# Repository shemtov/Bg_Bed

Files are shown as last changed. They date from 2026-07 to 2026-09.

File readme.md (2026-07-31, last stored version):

# BedSystem — clean start

Rev 4 architecture. One central panel, two bed boxes, one audio node, all wired.

---

## The one rule that fixes the confusion

**The code file is always `src/main.cpp`. Always. In every project.**

The test number lives *inside* the file, on the `#define TEST_NUMBER` line and in
the banner at the top and bottom. It is never in the filename.

That means:

- There is never a question of "which .cpp is the current one" — there is only one.
- You never get "multiple definition of setup()" from two files sitting in `src/`.
- To move to a new test, you **overwrite** `src/main.cpp`. You never add a file.

The old names — `panel_test040.cpp`, `bedbox_test0009.cpp` — are what caused the
mess. They stop here.

---

## Structure

```
BedSystem/
├── panel/                  ESP32-8048S043 touchscreen at the headboard
│   ├── platformio.ini
│   ├── include/lv_conf.h   <-- YOU MUST SUPPLY THIS
│   └── src/main.cpp        TEST 041  (ready)
│
├── bedbox/                 QuinLED-ESP32 + L298N under each bed
│   ├── platformio.ini      (your real TEST 0009 config)
│   └── src/main.cpp        <-- YOU MUST SUPPLY THIS
│
└── audionode/              WT32-ETH01 + PCM5102A, by the soundbar
    ├── platformio.ini      (ready)
    └── src/main.cpp        (not written yet — TEST 001)
```

Each of the three folders is a **separate PlatformIO project**. Open them one at a
time in VS Code with **File → Open Folder**, pointing at `panel`, `bedbox` or
`audionode` — never at `BedSystem` itself.

You can rename the `BedSystem` folder to anything you like. PlatformIO only cares
about the folder that directly contains `platformio.ini`.

---

## Three files you must bring from your PC

I cannot reconstruct these reliably, and guessing would waste your time:

**1. `panel/include/lv_conf.h`** — LVGL's configuration. Yours works; a guessed one
probably won't. Find it in your old panel project under `include/`. There is a
placeholder file next to it from the old Test 1 project — that one is for LVGL 8.4
and is only a reference, not a drop-in. Delete it once you've copied the real one.

**2. `panel/platformio.ini`** — I rebuilt one from the `#include` lines in your
code, and it should be close. But if you can find the file that actually built
TEST 040, **use that instead** and overwrite mine. Known-good beats deduced.

**3. `bedbox/src/main.cpp`** — your TEST 0009 bed box code. Never uploaded here.
Its `platformio.ini` is already in place and is the real one.

---

## First build

1. VS Code → File → Open Folder → `BedSystem/panel`
2. Copy your `lv_conf.h` into `include/`
3. Click ✓ in the bottom bar to build
4. Green SUCCESS, or paste the first red error

At boot the serial monitor should print:

```
=== PANEL — TEST 041 — LVGL UI + Settings ===
```

---

## Never lose the files again

Once this builds, do one of these — five minutes now saves an afternoon later:

- Add `panel/src/main.cpp`, `panel/platformio.ini` and the bed box equivalents to
  the **project knowledge** of this Claude project, so every future chat opens
  with the real code already loaded, or
- `git init` in `BedSystem`, push it to GitHub, and paste the repo URL into any
  new chat.

A `.gitignore` is included so the build folder never gets committed.

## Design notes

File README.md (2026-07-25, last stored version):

# Massage-Bed
panel and bedbox controling massage motors and  audio sound system via voice recodnition

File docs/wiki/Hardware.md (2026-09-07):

# Hardware

## Shemi BedBox
Board: QuinLED ESP32, ESP32-WROOM-32E.

### Diagnostic LEDs
Exactly 7 addressable LEDs are installed.

**PROVEN discovery:** the pixels are RGBW, requiring 32 bits per pixel. Earlier firmware used RGB/24-bit and produced the characteristic failure where only about five of seven physical LEDs responded and colors appeared random.

Current data path tested in the standalone LED test:
`GPIO23 -> external level shifter -> DIN`

Level shifter wiring used:
- LV = 3.3V
- HV = 5V
- common GND
- GPIO23 -> LV1
- HV1 -> first pixel DIN

## Massage controllers
L298N controllers, two motors per controller. Four controllers allow an 8-motor architecture.

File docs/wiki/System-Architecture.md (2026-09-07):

# System Architecture

## Core idea
BG Bed is a wired smart bedroom/bed system. Touch panels, BedBoxes and other nodes communicate over RS-485. The design deliberately minimizes unnecessary RF near the bed.

## Current major nodes
- Shemi 7-inch Waveshare ESP32-S3 touch panel
- Ira 7-inch Waveshare ESP32-S3 touch panel
- Shemi BedBox — QuinLED ESP32 WROOM-32E
- Ira BedBox — separate node
- Audio node
- Listener / voice node

## Current RS-485 facts
Shemi is the time source. Ira receives TIME and returns ACK. Shemi BedBox has been connected to the shared bus and has successfully parsed both frame types on hardware.

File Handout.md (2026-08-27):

<div dir="rtl" align="right">

# Bg_Bed — מסמך מסירה
**גרסה 18 — 24 באוגוסט 2026**

מחליף את Rev 17. מסמך עצמאי: הוא לבדו אמור לאפשר לשיחה חדשה להמשיך בלי ללמוד מחדש.

## 🔁 השינוי ב-Rev 18 — לוחות הבד־בוקס נעולים

**הכרעה של שמי, 24 באוגוסט:** שני הבד־בוקסים אינם אותו לוח, וההמתנה ל-`QuinLED`
שני מבוטלת.

- **`bedbox_shemi` — `QuinLED-ESP32`** (`ESP32-WROOM-32E`). קיים, מותקן, `TEST 012`.
- **`bedbox_ira` — `ESP32-S3-DevKitC-1 N16R8`** (ערכת פיתוח). טרם נכתב.

**המשמעות לקושחה:** זו לא העתקה. הליבה של ה-`S3` היא Arduino core 3.x, שבו
`ledcSetup`/`ledcAttachPin` הוסרו, ול-`ESP32-S3` יש **שמונה ערוצי `LEDC` בלבד** —
כולם ייצרכו על ידי שמונה המנועים. **פורט, לא copy-paste.**

## 🔁 השינוי ב-Rev 17 — הקו נעשה דו־כיווני

**הכרעה של שמי, 16 באוגוסט:** הקו לא נושא רק פקודות. **צומת האודיו מחזיר לפאנלים
את מה שמתנגן** — שם התחנה, כותרת השיר, וכל מה שהזרם מספק — **ושני הפאנלים
מציגים את זה**, של שמי ושל עירה.

עד עכשיו הפרוטוקול היה **ארבעה בתים בכיוון אחד**: הפאנל מצווה, הצומת מציית,
המסך מראה את מה שהפאנל *חושב* שקורה. מעכשיו המסך מראה את מה ש**באמת** קורה.

**זה לא סותר את מה שנכתב ב-Rev 16 על אודיו בקו.** אודיו גדול מהקו בארבעה סדרי
גודל. **טקסט קטן ממנו בשלושה.** ההבחנה נשמרת: אודיו לא עובר, טקסט עובר בקלות.

**המימוש המלא — סעיף 11.** התוספת היא מסגרת מורחבת לצד ההודעה בת ארבעת הבתים,
לא החלפה שלה. **תכנון בלבד — חומרת ה-`RS-485` טרם הגיעה ושום בית לא נשלח עדיין.**

---

## 🔒 השינוי הגדול ב-Rev 16 — כלל הפרטיות ננעל, וזיהוי עברית נפתר

### כלל נעול (שמי, 16 באוגוסט, בנחרצות)

**שום אודיו מחדר השינה לא יוצא מהחדר. לעולם.**
לא `Google Speech`, לא זיהוי בענן, לא אחסון בענן, לא העלאה מכל סוג.
**כל הזיהוי וכל ההקלטה נשארים בתוך הבית.** אין להציע שירותי ענן לפרויקט הזה שוב.

זה סוגר סופית את כיוון ה-`Google Speech` שנשקל קודם. מה שנשאר: מחשב מקומי, או
זיהוי על הצומת עצמו.

### ✅ הפתרון לעברית — `Edge Impulse` / keyword spotting

**התובנה:** זיהוי מילת מפתח הוא **סיווג צלילים, לא זיהוי דיבור.** המודל לעולם
לא לומד מה המילה אומרת ובאיזו שפה היא. הוא לומד לזהות **תבנית קול**.
**לכן עברית עובדת בדיוק כמו אנגלית** — למודל אין מושג שיש הבדל.

**כל מה שנכתב קודם על "עברית לא נתמכת" תקף לתמלול בלבד.** לטכניקה הזו זה לא חל.

- רץ על `ESP32-S3` — בדיוק צומת ההקשבה. לשבב יש מאיץ רשתות נוירונים מובנה.
- קיים פרויקט התחלה מוכן ל-`ESP32-S3-DevKitC-1` עם מיקרופון `I2S`.
- ההסקה מקומית לגמרי, שום אודיו לא עוזב בזמן שימוש.
- **אימון על הקולות של שמי ועירה עדיף על כל מנוע כללי** — אותם מיקרופונים,
  אותו מרחק, אותה אקוסטיקה. בעיה קלה בהרבה מלעבוד לכל העולם.
- **תכסיס:** לא לאמן משפטים שלמים אלא מילים קצרות ולשרשר אותן —
  wake ← מיקום ← מכשיר ← פעולה. שמונה מילים מאומנות ⇒ ~12 פעולות.

**⚠️ ההחלטה היחידה שנותרה פתוחה בכיוון הזה:** `Edge Impulse` היא פלטפורמת ענן
**לשלב האימון**. הדגימות מועלות לשרתים שלהם. זה לא אודיו פסיבי מחדר השינה אלא
הקלטה מכוונת ליד השולחן — אבל זה עדיין קול שיוצא מהבית. חלופה מקומית לחלוטין:
אימון עצמאי עם `TensorFlow Lite Micro`, יותר עבודה ובלי ממשק ווב.

**אם זה מתקבל — פקודות קול בעברית אפשריות בלי שום מחשב לינוקס.**
ההחלטה על מחשב הלינוקס מצטמצמת אז ל-`Spotify` בלבד.

---

## 🎵 Rev 15 — צומת האודיו מנגן (נשאר תקף)

**`TEST 010` רץ על חומרה, ורדיו אינטרנטי נשמע מהסאונדבר.** גלגלצ ניגן.
זו השרשרת המלאה, מאושרת מקצה לקצה:

`ESP32-S3` ← `W5500` אתרנט קווי ← ספריית אודיו ← `PCM5102A` ← ממיר אנלוגי-לדיגיטלי
← אופטי ← סאונדבר.

**התקלה שעלתה ערב שלם, והלקח:** לא נשמע כלום מ-`TEST 007` עד `TEST 009`, למרות
שהלוג הראה `playing yes` ברציפות. **הקושחה מעולם לא הייתה אשמה.** האשם היה
**קופסת הממיר האנלוגי-לדיגיטלי — היא הייתה תקולה.** החלפת הקופסה פתרה הכל.

**מה שמצא את זה — בדיקת הצליל (`TEST 009`):** בנייה שמסירה את הרשת, את הסטרימינג
ואת ספריית האודיו לגמרי, ומייצרת גל סינוס 440 הרץ בקוד ישירות אל ה-`I2S`.
**זו השיטה הנכונה לחלוקת בעיות אודיו לשניים** — היא הוציאה את הקושחה מהמשוואה
בבנייה אחת. שווה לזכור אותה לכל תקלת שמע עתידית.

---

## 1. מה זה

מערכת חכמה לחדר שינה של שמי ועירה, בנחשולים, ישראל. שני פאנלים מגע שולטים בעיסוי רטט
בשתי מיטות, ברדיו אינטרנטי, במזגן, באור, בתריס ובמאוורר. בהמשך גם תיעוד שינה
ופקודות קוליות.

**עקרון מנחה, נעול:** אפס קרינת `RF` ליד הראשים. כל התקשורת בין הלוחות קווית
(`RS-485`). רק צומת האודיו מחזיק רדיו — אך גם הוא מתחבר לרשת דרך **אתרנט קווי
(`W5500`)**, לא `WiFi`. ה-`WiFi` של כל הלוחות נשאר כבוי תמיד.

---

## 2. מבנה הריפו

`github.com/shemtov/Bg_Bed`, ענף `main`, תיקייה מקומית `C:\projects\Bg_Bed`

- `panel_shemi/` — הפאנל של שמי, `ESP32-8048S043`
- `panel_ira/` — הפאנל של עירה, `Waveshare ESP32-S3-Touch-LCD-4.3`
- `bedbox_shemi/` — `QuinLED-ESP32`, המיטה של שמי
- `bedbox_ira/` — `ESP32-S3-DevKitC-1`, המיטה של עירה — **טרם נכתב**
- `audionode/` — רדיו, מזגן, `RF` — ממתין ללוח
- `switcher/` — סקריפטים לגילוי ולשליטה ב-`Switcher Breeze`
- `pcb/` — נטליסט וטבלת חיבורים ללוח נושא. **הפרויקט נזנח לטובת הלחמה**
- `Handout.md` — המסמך הזה

**שני בד־בוקסים נפרדים בכוונה** — לוחות שונים לגמרי, `QuinLED` מול `ESP32-S3`,
מפות פינים שונות ו-`platformio.ini` שונה.

---

## 3. מוסכמות עבודה — לפי הכללים של שמי

- **תמיד קובץ שלם.** אף פעם לא `diff`, אף פעם לא "תשנה את השורה הזאת". שמי לא
  עורך קוד ביד — קלוד מבצע את השינוי ומספק את הקובץ להורדה.
- **מספר `TEST` עולה ב-1 בכל שינוי, בלי יוצא מן הכלל, בלי לקבץ.** חי בתוך הקובץ
  בלבד — באנר שלוש שורות ראשונות, `#define TEST_NUMBER`, ובאנר סוף הקובץ. שלושתם
  מתעדכנים יחד. **לעולם לא בשם הקובץ.** הקובץ תמיד `src/main.cpp`.
- **תשובות בעברית**, מונחים טכניים באנגלית בתוך `code marks`.
- **`GND` נכתב באנגלית, אף פעם לא "מסה".**
- **`L298N` הוא `בקר`**, לא "נהג" ולא "דרייבר".
- **לעולם לא לטעון שמשהו עובד/תוקן אלא אם נבדק על חומרה אמיתית.** שפה זהירה:
  "לא נבדק, יש לבנות לאישור".
- **לעולם לא לנחש.** לעבוד רק מעובדות — פלט טורי, צילומי מסך, תמונות. כשתקועים,
  לעצור ולאסוף עובדה (הדפסה טורית, סיבת reset) במקום להמשיך לנחש.
- **קישורי קניה:** תמיד `AliExpress` ראשון, `Temu` שני, `Amazon` שלישי. קישור
  ישיר לדף המוצר.
- `commit` דרך `GitHub Desktop`, עם מספר הגרסה בהודעה.
- כל תיקיית פרויקט נפתחת בנפרד ב-VS Code. **לעולם לא שורש הריפו.**
- נתיבים בלי אותיות עבריות — הכלים נחנקים עליהן.
- **מלכודת שכפול הקובץ:** הדבקה ל-VS Code לפעמים **מוסיפה** לקוד הישן במקום להחליף.
  התיקון: לחיצה ימנית על `main.cpp` ← `Delete` ← לגרור את הקובץ החדש ל-`src/`.

---

## 4. הפאנל של שמי — `panel_shemi`

`ESP32-8048S043`, מודול `ESP32-S3-WROOM-1 N16R8`, 16MB פלאש, 8MB `PSRAM` אוקטלי,
מסך 800×480 `RGB`, מגע `GT911`.

**קושחה: `TEST 085` — מותקן ועובד בחדר השינה.**

**פינים — כולם תפוסים, אין אף אחד פנוי:**

- `I2C`: `SDA` = `IO19`, `SCL` = `IO20`
- `BH1750` אור `0x23`, `SHT31` טמפ׳ ולחות `0x44`, `AT24C32` `0x57`,
  `GT911` מגע `0x5D`, `DS3231` שעון `0x68`, `BMP280` לחץ `0x76`
- `UART1`: `TX` = `IO17`, `RX` = `IO18`, דו־כיווני
- תאורה אחורית: `GPIO2`, `PWM` אמיתי
- `IO11`, `IO12`, `IO13` — **התפנו.** היו המיקרופון, שנותק

**`platformio.ini` — אסור לגעת:**
`platform = espressif32 @ 6.9.0` הכרחי בשביל `GFX 1.3.8`.
`-DLV_CONF_SKIP` — **אין `lv_conf.h` בשום מקום.** `-DLV_TICK_CUSTOM=1` הכרחי.

**מסך הבית — רשת 4 על 2, אריחים 175 פיקסלים:**
שורה 0: מסאז׳, רדיו, מזגן, מאוורר. שורה 1: אור, תריסים, הגדרות, וריק.

**ה-screensaver של שמי** הוא מכונת מצבים נקייה: `ST_UI` / `ST_SAVER` / `ST_PREVIEW`.
במצב saver LVGL מושהה, המגע נקרא ישירות, והשעון מצויר ב-`gfx` גולמי (raw). זה
המודל שהוכיח את עצמו — וממנו נלמד ה-screensaver החדש של עירה (סעיף 5).

---

## 5. הפאנל של עירה — `panel_ira`

`Waveshare ESP32-S3-Touch-LCD-4.3`, אותו מודול `N16R8`.

**קושחה: `TEST 079` — כל המסכים עובדים ומאושרים על החומרה.**

**מה בנוי ועובד (מאושר על החומרה):**
- מסך בית עם רשת אריחים (מסאז׳, רדיו, מזגן, מאוורר, אור, תריסים, הגדרות)
- מסך רדיו (`buildRadio`), מסך מסאז׳ (`buildMassage`), מסך הגדרות (`buildSettings`)
- מסך מזגן (`buildAC`) ומסך מאוורר (`buildFan`) — מועתקים מ-`panel_shemi`
- **כותרת עליונה במסך הבית** (`TEST 077`): שמאל `BG חדר שינה` (עברית), מרכז
  `TEST NNN`, ימין טמפרטורה + תאריך/שעה (placeholder עד שהשעון יגיע בקו)

**ה-screensaver — נכתב מחדש מהיסוד ב-`TEST 072`, ועבר דרך ייסורים ארוכים:**
- **המודל החדש:** ה-screensaver **אינו** מסך LVGL. הוא מצויר ישירות ב-`gfx`
  גולמי מעל מסך שחור, ודגל פשוט `saverActive` עוקב אחריו. זה חיסל **שתי** בעיות
  שעלו ימים: החפיפה של המסך הקודם, וההיתקעות במגע.
- **לקח מרכזי (`TEST 074`):** כשה-saver פעיל, **אסור לקרוא ל-`lv_timer_handler`**.
  אחרת מסך `About` (המתעדכן על טיימר) מצייר את עצמו **מעל** ה-saver. זו הסיבה
  שרק `About` חפף — הוא המסך היחיד שמתרענן תקופתית.
- **יציאה:** המגע נקרא ישירות בלולאה. שליש ימני = דרים־קאטצ'ר (החזקה = הקלטת
  חלום, stub טורי עד שצומת ההקשבה ייבנה). כל מגע אחר = יציאה הביתה.
- **מראה (`TEST 075`+):** חוגה אמיתית (`img_dial` 340×340) ודרים־קאטצ'ר אמיתי
  (`img_dream`) מצוירים ב-`draw16bitRGBBitmap`. מחוגים כקווים ב-10:10. הטמפרטורה
  בפונט `gfx` מובנה — **הערה:** הפונט המעוגל `FreeSansBold24pt7b` **לא קיים**
  בהתקנת ה-`GFX` הזו; אם רוצים פונט מעוגל צריך להמיר את `temp_big` לפורמט GFXfont.

**משימות פתוחות במסך הבית (לטסט הבא):** התאריך צריך לשבת **משמאל** לטמפרטורה,
לא מתחתיה.

**פינים:**
- `I2C`: `GPIO8` = `SDA`, `GPIO9` = `SCL`
- מגע `GT911` על `0x5D`, פסיקה `GPIO4`
- מרחיב `CH422G` — עונה על כל הבלוק `0x20` עד `0x3F`.
  `EXIO1` = איפוס מגע, `EXIO2` = תאורה, `EXIO3` = איפוס מסך
- `GPIO6` פנוי, יוצא במחבר `Sensor AD`
- `RS-485` על `GPIO15`/`GPIO16` דרך `SP3485`

**`platformio.ini`:** אותה פלטפורמה `6.9.0`, אבל **`qio_opi`** ולא `opi_opi` —
הפלאש רגיל, ה-`PSRAM` אוקטלי. `board_build.*` **ו-**`board_upload.*` שניהם נדרשים.
פונטים 20, 24, 28, 40. `monitor_rts`/`monitor_dtr` על אפס.

**חיישנים:** `SHT31` על `0x44` ו-`BH1750` על **`0x5C`** — לא `0x23`, כי שם יושב
המרחיב. **בלי `DS3231`** — השעה מגיעה בקו. **בלי `BMP280`**. **בלי מיקרופון** —
הוא בצומת ההקשבה/האודיו.

**קונפליקט מספרי פקודה שתוקן:** `CMD_AC_LIGHT` הועבר ל-`17` (היה `16`, התנגש
עם `CMD_AC_TIMER`).

---

## 6. הבד־בוקס של שמי — `bedbox_shemi`

`QuinLED-ESP32`, שישה מנועי רטט `12V`, שלושה `בקרים` `L298N`.
**קושחה: `TEST 012`**

**מנועים:** `m0` פין 13, `m1` פין 14, `m2` פין 18 (גדול), `m3` פין 19 (גדול),
`m4` פין 21, `m5` פין 22. אזורים `{0,0,1,2,3,3}`.
פינים נוספים למעבר לשמונה מנועים: **`GPIO26` ו-`GPIO27`** (נבדקו, לא `strapping`).

**חיווט כל `בקר`:** `12V` ל-`VS`, `GND` משותף חובה, `IN1`/`IN3` ל-`GND`,
`IN2`/`IN4` ל-`5V`, רק `ENA`/`ENB` ללוח. **ג׳מפרי `ENA`/`ENB` חייבים לרדת.**
`PWM` 20 קילו־הרץ. **התקנה עברה לילה שלם.**

**מנועים אושרו:** `12V`; גדולים `0.3A`, קטנים `0.1A`; שניהם מסתובבים גם ב-`5V`.

---

## 7. הבד־בוקס של עירה — `bedbox_ira`

**טרם נכתב.** לוח: **`ESP32-S3-DevKitC-1 N16R8`** — ערכת פיתוח, **לא** `QuinLED`.
שמונה מנועים, ארבעה `בקרים` `L298N`.

**נסגר ב-Rev 18:** אין יותר המתנה ל-`QuinLED` שני. `QuinLED` נשאר רק אצל שמי.
שני הבד־בוקסים הם לוחות שונים, וזו החלטה ולא מצב זמני.

**מפת פינים מוצעת — טרם נבדקה על חומרה:**
מנועים על `4`, `5`, `6`, `7`, `15`, `21`, `38`, `39`.
`SP3485`: `TX` = `17`, `RX` = `18`, `RE`/`DE` = `16`.

**אזהרת פורט (לא לגלוש עליה):** ה-`S3` רץ על Arduino core 3.x. `ledcSetup` ו-
`ledcAttachPin` **הוסרו** — ה-`API` החדש הוא `ledcAttach`. בנוסף ל-`ESP32-S3` יש
**שמונה ערוצי `LEDC`**, ושמונת המנועים יצרכו את כולם: לא נשאר ערוץ `PWM` לשום
שימוש אחר בלוח הזה.

---

## 8. צומת האודיו — `audionode`

**החומרה הגיעה, והלוח נבנה והולחם.** (id 9 בקו)

### ✅ מאושר על חומרה — `TEST 010` מנגן רדיו

**מצב נוכחי: עובד.** מנגן גלגלצ מהסאונדבר, מתחיל לבד בלי מחשב מחובר.

**פקודות בטורי:** `l` רשימת תחנות · מספר לניגון · `+`/`-` עוצמה · `s` עצירה ·
`i` מידע · **`u <url>` לנגן כל כתובת שהיא — בלי בנייה מחדש.** זו הדרך לצוד תחנות
חדשות בלי לגעת בקוד.

**`autoplay`** מוגדר לתחנה 0, שלוש שניות אחרי קבלת כתובת. לביטול: `AUTOPLAY_STATION` ל-`-1`.

**תחנות בטבלה (כתובות מאומתות מרשימות ציבוריות):**
| # | תחנה | כתובת |
|---|---|---|
| 0 | גלגלצ | `http://glzwizzlv.bynetcdn.com/glglz_mp3` — `http` פשוט, הידידותי ביותר |
| 1 | כאן 88 | `https://playerservices.streamtheworld.com/api/livestream-redirect/KAN_88.mp3` |
| 2 | Groove Salad | `https://ice5.somafm.com/groovesalad-128-mp3` |
| 3 | Drone Zone | `https://ice5.somafm.com/dronezone-128-mp3` |
| 4 | Deep Space One | `https://ice5.somafm.com/deepspaceone-128-mp3` |
| 5 | Lush | `https://ice5.somafm.com/lush-128-mp3` |

`SomaFM` מזהירים ש-`ice5` יכול לזוז; שרת חלופי הוא `ice3` באותו נתיב.

**שמי ביקש וטרם נמצאו:** whiskey blues, מפלי מים/טבע, מדיטציה, `Pink Floyd Radio`.
לצוד אותן עם פקודת `u`.

**ספריית האודיו:** `https://github.com/schreibfaul1/ESP32-audioI2S.git` — **git master,
לא הנעילה הישנה ל-`3.4.0`.** הנעילה ההיא נבחרה לליבה 2.x על ה-`ESP32-CAM` ואינה
מתאימה כאן. master עובד עם ליבה 3.x.

### מה מאושר על חומרה — `TEST 006`, בדיקת האתרנט

הקושחה נכתבה **מאפס** (לא העתקה מ-`TEST 004`) ורצה על הלוח החדש. פלט הטורי אישר:

- `chip` — `ESP32-S3` rev 2, שני ליבות, 240 מגה־הרץ
- `flash` — `16777216` בתים. **16 מגה־בייט מאושר.**
- `psram` — `8388608` בתים. **8 מגה־בייט מאושר ועובד.** (תיאור הלוח ב-`PlatformIO`
  טוען "No PSRAM" — **התיאור שגוי**, השבב עצמו מדווח אחרת. לא ללכת לפי התיאור.)
- `reset` — `power on`. אתחול נקי, בלי נפילת מתח.
- `eth` — `LINK UP` תוך שתי שניות, כתובת תוך שלוש
- כתובת שהתקבלה: `192.168.1.195`, `gateway`/`dns` `192.168.1.1`
- `MAC` — `12:C1:9F:CD:37:C9` ← **לשריין כתובת קבועה בנתב**
- מהירות — `100 Mbps full duplex`
- פתירת שם ופתיחת `socket` החוצה — **הצליחו**
- יציבות — 84 שניות רצופות, `heap` `311744` **זהה בכל שורה**, אפס דליפה

### מיפוי הפינים — מאושר על חומרה, לא הצעה

| רכיב | פין | `GPIO` |
|---|---|---|
| `W5500` | `SCLK` | 12 |
| `W5500` | `MOSI` | 11 |
| `W5500` | `MISO` | 10 |
| `W5500` | `SCS` | 9 |
| `W5500` | `INT` | 8 |
| `W5500` | `RST` | 7 |
| `PCM5102A` | `BCK` | 14 |
| `PCM5102A` | `LCK` | 2 |
| `PCM5102A` | `DIN` | 13 |

**אסור לגעת:** `GPIO26` עד `GPIO37` — תפוסים על ידי הפלאש והזיכרון החיצוני.
פינים שנשארו פנויים: 1, 4, 5, 6, 15, 21, 38, 47, 48.
שמור לקו `RS-485`: `TX` 17, `RX` 18, בקרת כיוון 16 (רק אם הממיר דורש).

### חומרה — מה שיושב על הלוח

- מוח: `ESP32-S3-WROOM-1 N16R8`
- אתרנט: `W5500` (HanRun HR911105A). **מאושר: למודול יש מייצב על הלוח והזנה
  בחמישה וולט תקינה.** הכניסות סובלות חמישה וולט, אין צורך בממיר מתחים.
- יציאת אודיו: `PCM5102A` → `3.5mm` → ממיר אנלוגי-לדיגיטלי → אופטי → סאונדבר.
  **אין צורך במגבר `TPA3116`.**

### גשרי ההלחמה של ה-`PCM5102A` — מאומת מהתיעוד

| גשר | תפקיד | לאן |
|---|---|---|
| `H1L` | `FLT` מסנן | `L` |
| `H2L` | `DEMP` הדגשה | `L` |
| `H3L` | `XSMT` השתקה | **`H`** |
| `H4L` | `FMT` פורמט | `L` |
| רפידה ליד פין השעון | `SCK` | ל-`GND` |

**`H3L` לצד הנמוך = השתקה מוחלטת, אפס צליל.** זו הסיבה הנפוצה ביותר ל"אין קול",
וברבים מהלוחות זה מצב ברירת המחדל מהמפעל.

### סביבת הפיתוח — מה שנפתר בכאב

`audionode` הוא הפרויקט היחיד שרץ על ליבה 3.x. הפאנלים נשארים על
`espressif32 @ 6.9.0`. **לא לאחד ביניהם.**

```ini
platform = https://github.com/pioarduino/platform-espressif32/releases/download/stable/platform-espressif32.zip
board = esp32-s3-devkitc-1
board_build.arduino.memory_type = qio_opi
board_build.partitions = default_16MB.csv
board_upload.flash_size = 16MB
board_upload.maximum_size = 16777216
```

שלוש תקלות התקנה שנפתרו, לפי הסדר:
1. `Failed to install Python dependencies into penv` — הסביבה הווירטואלית פגומה.
   פתרון: לשנות שם ל-`penv_old` ב-`C:\Users\User\.platformio`, לתת לה להיבנות מחדש.
2. `ModuleNotFoundError: No module named 'certifi'` — אותה בעיה, ביטוי אחר.
3. `FileNotFoundError` על נתיב ארוך במיוחד — **מגבלת 260 התווים של `Windows`.**
   פתרון: `regedit` → `HKEY_LOCAL_MACHINE\SYSTEM\CurrentControlSet\Control\FileSystem`
   → `LongPathsEnabled` = `1` → **אתחול מחשב** → למחוק `.platformio\.cache`.

**שגיאות אדומות של `Access is denied` על קבצי `.git` בתוך חבילת ה-framework —
לא מזיקות.** זו פעולת ניקוי שנכשלת, לא שלב בנייה.

### מלכודות `API` בליבה 3.x

`ETH` **אין** לו `hostByName`. במקום זה: `NetworkClient::connect(hostname, port, timeout)`
פותר שם ופותח `socket` בקריאה אחת, ואז `client.remoteIP()` מחזיר את הכתובת.

### `TEST 011` → `TEST 014` — נכתבו, טרם רצו על חומרה

| `TEST` | מה נוסף |
|---|---|
| 011 | דף רשת על פורט 80 — מה מתנגן, עוצמה, עצירה, כפתורי תחנות, תיבת כתובת חופשית, ו-6 `presets` **שמורים בפלאש** (שורדים ניתוק חשמל) |
| 012 | מתג `USE_WIFI` (ברירת מחדל 0 = קווי). מצב שולחן עבודה נבדק ועבד מול `Zyxel_C46D` |
| 013 | `OTA` דרך הרשת · דף `/log` · **טרמינל רשת חי על פורט 2323** |
| 014 | תיקון שורה אחת — הצהרה מקדימה של `handleLine` מעל `pollLogServer` |

**`OTA`:** שם מארח `audionode`, סיסמה `bgbed`. הרדיו **נעצר אוטומטית** לפני צריבה
כדי ששידור לא יתנגש בהעלאה. ב-`platformio.ini` יש שלוש שורות מוכנות בהערה
(`upload_protocol = espota`).

**טרמינל הרשת (פורט 2323):** מתחברים מה-`PC` בכל תוכנת טרמינל. מקבלים מיד את
ההיסטוריה, ואז פלט חי — **ואפשר להקליד את אותן פקודות** של המוניטור בכבל.
זה מה שמחליף את כבל ה-`USB` באמת.

**דף `/log`:** 120 השורות האחרונות, קריא מהטלפון. כפתור בתחתית דף הרדיו.

> **⚠️ להשאיר את כבל ה-`USB` נגיש** עד ש-`OTA` יעבוד כמה פעמים. העלאה שנכשלת
> באמצע עשויה לדרוש כבל כדי להתאושש. **לא לסגור את הלוח מאחורי רהיט באותו יום
> שמפעילים `OTA` בפעם הראשונה.**

> **⚠️ סיכון פרטיות בריפו:** ב-`TEST 012` סיסמת ה-`WiFi` נכתבה לתוך הקובץ,
> **והריפו ציבורי.** לפני `commit` — להחזיר `placeholder` ולוודא `USE_WIFI 0`.

### פתוח

- אינדקסי התחנות בפאנל ובצומת לא תואמים — **הפתרון נבחר ב-Rev 17:** הצומת
  שולח את השמות בקו (מטען `0x02`), והפאנל מפסיק לנחש. ראה סעיף 11
- **לבנות ולצרוב `TEST 014` בכבל** (אי אפשר להתקין `OTA` דרך `OTA`)
- דף הרשת מעולם לא רץ על חומרה
- **החלטת איחוד `audionode` + `listener`** — ראה סעיף 10

---

## 9. צומת ההקשבה — `listener` (id 8)

**החומרה ביד** — הלוח והמיקרופונים. **הקושחה טרם נכתבה.**

תפקיד: להאזין לשינה של שני האנשים ליד המיטה — **נחירות, נשימה, ותיעוד שינה**,
וכן **פקודות קול** ותיעוד חלומות (Dreamsaver). הכל קווי, אפס `RF`.

**חומרה:**
- מוח: `ESP32-S3-DevKitC-1 N16R8` (ל-`DevKitC` אין חריץ כרטיס משלו)
- **שני `INMP441`** — מיקרופון אחד ליד כל ראש (זרוע קצרה, כבל מסוכך)
- אחסון — **הוכרע 16 באוגוסט: לקנות מודול `microSD` פשוט ב-`SPI`.**

  **תיקון לגרסה הקודמת:** נכתב קודם ש-`SD_MMC` בסיב אחד הוא "הנכון אם מקליטים
  אודיו". **החישוב מראה שזה היה זהיר מדי.** ההקלטה היא 16 קילו־הרץ, 16 סיביות,
  מונו — כ-**32 קילו־בייט לשנייה**. `SPI` מעביר את זה במרווח ביטחון עצום.
  **`SPI` רגיל מספיק לגמרי**, פחות פינים וקוד פשוט יותר.

  **⚠️ שני מודולים שונים לגמרי נקראים "3.3 וולט":**
  - **המודול הכחול הנפוץ** נושא מייצב `AMS1117` וממיר רמות `74LVC125`. הוא בנוי
    ל-`Arduino` של חמישה וולט. **בהזנת 3.3 וולט הוא לרוב לא מצליח לעלות** — למייצב
    אין מספיק מרווח. זו התלונה הנפוצה ביותר על הלוחות האלה, ו"הפתרון" של אנשים
    (להזין חמישה וולט) שם לוגיקה של חמישה וולט על קווי הכרטיס.
  - **מה שצריך:** הסוג החשוף — רק השקע וכמה רכיבים פסיביים, **בלי מייצב ובלי ממיר
    רמות**. לוח קטן יותר, שישה פינים, מסומן 3.3 וולט בלבד.

  **לקנות כמה** — עולים אגורות, לאחד תהיה הלחמה קרה, וכדאי אחד על השולחן ואחד במיטה.
  **כרטיס קטן** — 8 או 16 ג'יגה־בייט, `Class 10`. כרטיסים ענקיים לא מהירים יותר
  ולפעמים בררניים יותר בעלייה.

- **❌ נדחה: `MP3-TF-16P` / `DFPlayer Mini`.** שמי שאל אם אפשר להשתמש בו כקורא
  כרטיסים. **לא — וזו סיבה מבנית, לא פרט שאפשר לעקוף.** זה נגן `MP3` שלם:
  שקע, מפענח, `DAC` ומגבר קטן. **חריץ הכרטיס מחובר לשבב המפענח שבתוך המודול,
  לא למעבד.** ה-`ESP32` לעולם לא רואה את הכרטיס ולא יכול לפתוח בו קובץ.
  הוא יכול רק לנגן קבצים שכבר הועלו מ-`PC` — **כלומר נכשל בדיוק במה שנדרש:
  כתיבה.** בנוסף, לוחות `V3.0` הם שכפולים עם כמה שבבי מפענח שונים בפנים שלא
  מגיבים זהה לאותן פקודות.

**התכסיס שחוסך פינים — שני מיקרופונים על אותם שלושה חוטים:**
ל-`INMP441` יש פין `L/R`. **קושרים `#1` ל-`GND`** (ערוץ שמאל = כרית שמי)
**ו-`#2` ל-`3V3`** (ערוץ ימין = כרית עירה). שניהם חולקים `BCK`, `WS`, `SD` —
**אפס פינים נוספים**, שני ערוצי `I2S` בפריים אחד. ההשוואה בין הערוצים היא מה
שמייחס נחירה לצד הנכון (הפרש ≥6 `dB`, אחרת "לא ודאי").

**חיבור לקו:** `RX` מהקו התחתון, `TX` לקו העליון דרך דיודה `1N4148`, 12V אחרי
`F3`, `GND` לנקודת הכוכב.

**הוחלט 15 באוגוסט — אין מיקרופון באף פאנל.** המיקרופונים חיים אך ורק על צומת
ההקשבה. בפאנל של שמי זה כבר המצב בפועל (`IO11`/`IO12`/`IO13` התפנו). בפאנל של
עירה מעולם לא היה. **תוצאה:** חריצי הכרטיס בשני הפאנלים משתחררים לשימוש.
בפאנל של עירה הכרטיס עובד ב-`SPI` ופין ה-`SD_CS` מונע דרך `EXIO4` של ה-`CH422G`,
כלומר **אפס פינים נוספים של המעבד**. בפאנל של שמי צריך עוד לוודא את מצב הפין
הרביעי (`CS`).

**רעיון שנשקל ונדחה:** לוח שלישי ייעודי להקלטת חלומות. נדחה כי המיקרופונים כבר
על צומת ההקשבה, התוספת לקושחה זעירה, והלוח השלישי לא פותר את ההשמעה אלא מזיז
אותה. **הפתרון המועדף:** ההקלטה יושבת על צומת ההקשבה, ולהשמעה נמתח **חוט ייעודי
קצר** בין צומת ההקשבה לצומת האודיו — לא הקו הראשי. בקצב גבוה זה מעביר ~90 קילו־בייט
לשנייה מול ~8 שנדרשים. פי עשר ממה שצריך.

---

## 9א. מחקר הנחירות ודום הנשימה — מה שנמצא (לא לבזבז שוב)

**זיהוי אקוסטי של נחירות ודום נשימה עובד — מגובה במחקר:**
- מחקר `JCSM`: טלפון על החזה של 50 מטופלים בזמן `polysomnography`. זמן נחירה
  התאם למעבדה `r=0.93`; מדד ה-`RDI` המשוער התאם ל-`AHI` האמיתי `r=0.94`.
  לאבחון `OSA` ב-`AHI≥15`: רגישות 0.70, סגוליות 0.94.
- גישת `ML` על צלילי נשימה: **רגישות 94%, סגוליות 87%** על 14,500+ קטעים של
  30 שניות; ה-`AHI` המשוער נבדל בממוצע ב-4.3 אירועים לשעה.
- אלגוריתם מסחרי לזיהוי נחירה: רגישות 86.3%, סגוליות 99.5% — **נחירה עצמה קלה
  לזיהוי אמין.**

**המנגנון — איך מזהים דום נשימה (חשוב!):** לא מזהים דום נשימה על ידי שקט. שקט
דו־משמעי (נשימה שקטה, מיטה ריקה, ראש מופנה — כולם נשמעים זהה). מזהים אותו לפי
**התבנית: נחירה סדירה ← שתיקה ארוכה חריגה ← נשיפת התאוששות (gasp) חזקה.**
ה-`gasp` הוא מה שהופך את זה מזיהוי לניחוש.

**האלגוריתם (רוב החלקים כבר נבנו ל-wake word):**
1. דגימה ב-16 קילו־הרץ, 24 סיביות בחריצים של 32, סטריאו
2. **אנרגיית פס:** נחירה חיה בעיקר מתחת ל-600 הרץ. `bandpass` 100–600 הרץ +
   `RMS` לכל פריים של 25 מילי־שניות — **בלי `MFCC`**
3. רצפת רעש אדפטיבית (כבר קיים מ-`TEST 056`)
4. **אירוע נחירה** = פרץ 0.3–2.5 שניות, מעל הרצפה, **חוזר כל 2–5 שניות** —
   המחזוריות היא קצב הנשימה, וזה מה שמבדיל נחירה ממכונית חולפת
5. **ייחוס** לפי הפרש ערוצים
6. **מועמד לדום נשימה** = היה נוחר סדיר, אז **≥10 שניות שקט**, שמסתיים ב**פרץ
   חזק מהממוצע האחרון**. שלושת התנאים — אחרת מתעד כל יציאה לשירותים
7. **לתעד, לא לפעול** — בהתחלה

**מה לעשות עם זיהוי — ההמלצה החזקה:** **שלושה שבועות רק להקליט, בלי לפעול.**
כל בוקר הפאנל מציג שורה אחת לכל אדם: דקות נחירה, נחירות לשעה, מספר הפסקות מעל
10 שניות, ההפסקה הארוכה. **הלוג שווה יותר מכל רטט** — זו דאטה לרופא, וזו הדרך
היחידה לדעת אם התערבות עושה משהו. רטט מליל ראשון = לעולם לא תדע את קו הבסיס.

**גבולות כנים:** דום נשימה **שקט** בלתי נראה (מרכזי, או חסימתי בלי נחירה — אין
חתימה אקוסטית). **אין מדידת חמצן** — ה-`desaturation` הוא מה שמזיק, ומיקרופון
לא רואה אותו. גם המחקר עם הטלפון על החזה החמיץ ~30% מהמקרים הבינוניים. **זה כלי
סינון ותיעוד, לא אבחון.** אם הלוג מראה הפסקות סדירות — זה הרגע להזמין בדיקת שינה
(זמינה בקופות בישראל), לא לכוונן ספים.

**פרטיות — הוחלט:** **אודיו לעולם לא נשמר — רק אנרגיות פס וחותמות זמן.** שום
דבר לא עוזב את הרכיב (אין `RF`). עירה אישרה מיקרופונים **לנחירות בלבד**.

**בקרת מיקום המיטה (התגובה) — מה שנמצא:**
- **הדרך המוכחת היא מניעתית, לא תגובתית:** לזהות שכיבה על הגב ולעודד גלגול —
  לא לזהות דום נשימה ולעצור אותו. פטנט `US 11,096,849` (Sleep Number):
  מצב נגד־נחירות שמרים מעט את הראש (הרמה קטנה מפחיתה רטט רקמה רכה, וגם מעודדת
  שינוי תנוחה). זה בדיוק "מצב חדר שינה" שלנו.
- **אזהרה הנדסית:** מחקרים על רטט לעצירת דום נשימה השתמשו ב-200–300 הרץ (הפס
  של קולטני `Pacinian`). **מנועי ה-`ERM` שלנו רחוקים מזה** — ב-12V הם 50–66
  הרץ. יורגש כרעד, לא כזמזום החד של המחקרים. לכן **התגובה שלנו היא הרמת ראש,
  לא רטט לעצירת אירוע.**
- זירת הפטנטים צפופה מאוד (משפחת Franceschetti, ZEEQ smart pillow ועוד). **לא
  מעכב בנייה לעצמנו — רלוונטי רק אם אי־פעם נמכור.**

---

## 10. זיהוי קול ופקודות — סטטוס ההחלטות

### ⚠️ תיקון חשוב 15 באוגוסט — `Vosk` **אינו** תומך בעברית

רשימת השפות הנתמכות של `Vosk` כוללת יותר מעשרים שפות — אנגלית, גרמנית, ערבית,
פרסית, יוונית, טורקית ועוד — **ועברית אינה ברשימה.** אין מודל עברית. הכיוון הזה
סגור, ומה שכתוב בגרסאות קודמות של המסמך היה שגוי.

**`Whisper` כן תומך בעברית**, ורץ על `Raspberry Pi 5`: שני המודלים הקטנים ביותר
עומדים בקצב דיבור חי, והבינוני רץ בערך בחצי מהמהירות ומתאים רק לעיבוד ברקע.

**אבל הדיוק בעברית נמוך.** מודל עברית קטן מכוונן נעצר סביב **55% שגיאת מילים** —
יותר ממחצית המילים שגויות.

**המסקנה המעשית:** המספר הזה תקף ל**תמלול חופשי**. לרשימה **סגורה** של עשר פקודות
ידועות מראש הוא הרבה פחות רלוונטי — משווים את התוצאה לעשר האפשרויות ובוחרים את
הקרובה. **פקודות עברית קבועות: אפשרי. הכתבה חופשית בעברית: לא.**
(שווה לבדוק את `ivrit-ai`, פרויקט ישראלי עם נתוני אימון בעברית.)

**הוחלט מוקדם בפרויקט, ועדיין תקף:**
- **`ESP-SR` (של Espressif) לא תומך בעברית**, ורץ רק על `ESP32-S3`.
- זיהוי קול חופשי (כמו Alexa) דורש שרת ענן — מתנגש עם עקרון הפרטיות/`RF`.

**מה שכן אפשרי:** wake word (למשל "BG") + מספר **פקודות אנגלית קבועות מראש**
(`ESP-SR` MultiNet, עד ~200 פקודות, מקומית על `ESP32-S3`).

**שמי מעוניין בפקודות קול** ("BG start radio", "BG start Spotify", "BG start
massage") כדי לא ללחוץ על מסכים כל הזמן. **שיקול עומס פתוח:** אם ה-`audionode`
עושה בו-זמנית אתרנט + רדיו + `DAC` + הקלטה + `ESP-SR`, זה אולי יותר מדי ל-`S3`
אחד. אפשרות: מוח `S3` נפרד לזיהוי קול.

### 16 באוגוסט — שתי הכרעות ששינו את התמונה

**1. הענן סגור.** ראה הכלל הנעול בראש המסמך. `Google Speech` ירד מהשולחן.

**2. `Edge Impulse` פותר את העברית מקומית.** ראה בראש המסמך. אם שלב האימון
בענן מתקבל — **אין צורך במחשב לינוקס בשביל קול בכלל.**

### ❌ למה אי אפשר להעביר אודיו ב-`RS-485`

שמי שאל אם צומת ההקשבה יכול לתפוס פקודה ולשלוח אותה בקו לניתוח. **הרעיון נכון,
הצינור שגוי:**

שלוש שניות דיבור ≈ **100,000 בייט**. הקו רץ ב-115200 סיביות לשנייה ≈ **11,000
בייט לשנייה** במקרה הטוב, והוא משותף עם העיסוי, השעון והשאר.
כלומר שלוש שניות אודיו יתפסו את **כל הקו לעשר שניות** ויחסמו כל מכשיר אחר.
הקו תוכנן להודעות של ארבעה בייטים. אודיו גדול ממנו בארבעה סדרי גודל.

**שלושה נתיבים שכן עובדים:**
1. אתרנט משלו לצומת ההקשבה (`W5500` נוסף) — הקו נשאר פנוי.
2. **דרך צומת האודיו** — החוט הפרטי בין הצמתים כבר מתוכנן להשמעת חלומות.
   לשלוח את האודיו באותו חוט, וצומת האודיו (שכבר ברשת) מעביר הלאה.
   **אפס חומרה חדשה — זה הנתיב המועדף.**
3. מיקרופון ישירות על המזהה — פשוט בתוכנה, אבל כבל מיקרופון ארוך ליד חיווט
   מנועים הוא בדיוק המקום שבו רעש חשמלי מנצח.

**הארכיטקטורה הנכונה:** מילת ההשכמה מזוהה **על הצומת עצמו** — מקומי וזול, וזה
אומר שהמיקרופונים **לא משדרים כל הלילה**, רק שלוש שניות אחרי מילת ההשכמה.
אחר כך השלוש שניות עולות בחוט הפרטי, ו**פקודה של ארבעה בייטים חוזרת בקו.**
קטן נכנס, קטן יוצא. הקו נושא רק את התוצאה.

**עירה אישרה מיקרופונים** לתיעוד נחירות בלבד — כל שימוש אחר בקול הוא שאלה חדשה.

---

### ⚠️ ההחלטה הפתוחה הגדולה ביותר בפרויקט — האם נכנס מחשב לינוקס קטן

**ההבחנה שמפשטת הכל:** `Spotify` דורש לינוקס. עברית דורשת לינוקס. **אלו לא שתי
בעיות אלא אותה בעיה.** מי שפותר אחת מקבל את השנייה כמעט בחינם.

**אם נכנס מחשב:** `Spotify` דרך `librespot` (בוגר ויציב, שנות אור מהפתרון המשובץ),
עברית דרך `Whisper`, ואפשר גם להעביר אליו את הרדיו.

**הבעיה שנשארת פתוחה גם אז:** המיקרופונים חייבים להיות ליד הראשים, המחשב חייב
להיות רחוק מהמיטה. שלוש דרכים להעביר קול ביניהם:
1. מילת הפעלה מזוהה מקומית על הלוח שליד המיטה, ורק ~3 שניות נשלחות למחשב
   (~90 אלף בתים, שנייה אחת על חוט ייעודי מהיר). זול, אבל מילת ההפעלה באנגלית בלבד.
2. חיבור רשת משלו ללוח שליד המיטה — נקי, אבל עוד מודול ועוד חוט.
3. מיקרופון ישירות למחשב בכבל ארוך — פשוט תוכנתית, מסוכן מבחינת רעש חשמלי.

**התקשורת עם המחשב היא לא הבעיה** — שלוש דרכים, כולן עובדות: להצטרף לקו הקיים
עם ממיר (הוזמנו חמישה), לדבר דרך הרשת (שניהם קוויים וכבר על אותה רשת), או חוט
טורי ישיר. **המכשול היחיד בקו:** לינוקס לא מדייק בתזמון שחרור הקו כמו מיקרובקר —
לבחור ממיר שמחליף כיוון **בחומרה**, לא כזה שדורש שליטה בתוכנה.

**הסיכונים האמיתיים במחשב הם במקום אחר:** כרטיס זיכרון שנשחק בעבודה רצופה
(לאתחל ממכונן חיצוני או מערכת קבצים לקריאה בלבד); זמן עלייה של חצי דקה מול
שנייה במיקרובקר — **כל מה שקריטי נשאר על הלוחות**; מאוורר בחדר שינה = כישלון,
צריך קירור פסיבי או מיקום מחוץ לחדר; ורשת אלחוטית ובלוטות׳ מובנים שצריך לכבות
בהגדרה.

**ההחלטה טרם התקבלה.**

---

### `Spotify` — מה שנבדק לעומק 15 באוגוסט

**הפתרון המשובץ (`cspot`) — לא מומלץ:**
- לא ספרייה שמוסיפים לרשימת התלויות. נבנה ב-`ESP-IDF` עם `CMake`, `protobuf`
  ו-`mbedTLS`. מתנגש עם ספריית האודיו שלנו על אותה יציאה.
- פורמט מוצפן וכבד לפענוח מ-`MP3`. דיווחי קריסות ואיפוסים ברגע ההתחברות.
- מונדס לאחור — נשבר כש-`Spotify` משנה משהו.
- **הרוצח:** `cspot` הוא **מקלט** בלבד, ומכשירי `cspot` **לא מופיעים** ברשימת
  המכשירים של ממשק הרשת של `Spotify`. אין למי לשלוח פקודה. **הפאנל לא יוכל לשלוט.**

**הפתרון על לינוקס (`librespot`) — עובד, ומאומת אצל אחרים:**
- קיים משתמש שמריץ בדיוק את התרחיש הזה: מחשב קטן שנשלט מטאבלט על הקיר ומפקודות קול.
- **התנאי הקריטי:** להריץ אותו **עם פרטי ההזדהות** של החשבון. זה מה שהופך אותו
  לנשלט מבחוץ. אם הוא רק "מתגלה ברשת" — הוא לא בהכרח נשלט.
- **מלכודת שפוגעת בדיוק בתרחיש שלנו:** העברת ניגון עובדת רק אם `Spotify` ניגן
  ברבע השעה האחרונה. התקן שישב בטל כל הלילה — בעייתי. יש גם דיווחים שההתקן נעלם
  מהרשימה אחרי שעות של חוסר פעילות.
- **הפתרון למלכודת:** לא לשלוח את פקודת הניגון דרך `Spotify` בכלל. המחשב מריץ
  שירות קטן משלו שמאזין לפאנל **ישירות**, והוא אומר לנגן המקומי מה לעשות.
  ממשק הרשת של `Spotify` נחוץ אז רק למשוך שמות פלייליסטים.
- **משפטית:** הפרויקט עצמו כותב שהשימוש בקוד הזה מול `Spotify` כנראה אסור מבחינתם,
  והשימוש על אחריות המשתמש.

**איך זה ייראה על המסך:** הפאנל **לא יקבל מסך מהמחשב** — אין בו דפדפן ואין שולחן
עבודה מרוחק. במקום זה: המחשב מושך את שמות הפלייליסטים ושולח **טקסט בלבד** (כמה
מאות בתים), **הפאנל מצייר את הרשימה בעצמו** באותו סגנון של שאר המסכים, נגיעה
בשורה שולחת מספר, והמחשב מנגן. מבחינת המשתמש זה בדיוק מה שביקש.
**מגבלות:** רשימה קצרה (~20 שורות), לא חיפוש בכל הקטלוג; ושמות בעברית דורשים
כיסוי מלא בפונט של הפאנל.

**המלצה:** לא לשים את `Spotify` בבניית צומת האודיו. לסיים אתרנט ורדיו, ולהשאיר
את `Spotify` כשאלה נפרדת שתלויה בהחלטת המחשב.

---

## 11. תקשורת — `RS-485`

**הוחלט.** הפאנל של עירה מוציא **רק `RS-485`** דרך `SP3485`. חמישה מודולי `RS-485`
הוזמנו. **ה-transceiver עבור `panel_shemi` הוזמן — טרם הגיע (דגם מדויק נדרש).**

**חיווט:** זוג מפותל, `A` ל-`A`, `B` ל-`B`, `GND` משותף. נגד 120 אוהם **בשני
קצות הקו בלבד**. `panel_shemi` הוא ה-bus arbiter; השעון (`DS3231`) עובר ממנו
לכל האחרים בקו.

**פרוטוקול, ארבעה בתים `{bedId, cmd, target, value}`:**
- `0` כיבוי, `1` הכול, `2` אזור, `3` מנוע, `4` תוכנית, `5` טיימר
- `10` `AC_POWER`, `11` `AC_TEMP`, `12` `AC_MODE`, `13` `AC_FAN`, `14` `AC_SWING`,
  `16` `AC_TIMER`, `17` `AC_LIGHT`
- `15` `RF` — **יעד 0 תריס, 1 אור, 2 מאוורר**
- `18` `FAN_POWER`, `19` `FAN_SPEED`, `20` `FAN_TIMER`, `21` `FAN_LIGHT`
- `22` `RADIO_PLAY` (יעד = אינדקס תחנה), `23` `RADIO_STOP`, `24` `RADIO_VOL`
  (0..21), `25` `RADIO_SLEEP` (דקות)
- עולה מהבד־בוקס: `20` רמת אזור

> **התנגשות מספרים שקיימת כבר היום:** `20` משמש גם `FAN_TIMER` בירידה וגם "רמת
> אזור" בעלייה. זה עובד רק כי הכיוון מפריד ביניהם. **קודים חדשים לא ממחזרים
> מספר קיים** — ראה 26/27 למטה.

---

### 🔁 Rev 17 — הערוץ החוזר: מה מתנגן עכשיו

**מה שהתבקש:** שם התחנה, כותרת מה שמתנגן, וכל מה שהזרם מוסר — חוזר בקו ומוצג
**בשני הפאנלים**.

#### למה זה אפשרי, בניגוד לאודיו

שלוש שניות דיבור הן כמאה אלף בתים — ולכן אודיו לא עובר בקו (סעיף 10).
**כותרת שיר היא 60 עד 120 בתים, ומשתנה פעם בשלוש דקות.** גם אם שואלים כל שתי
שניות ומקבלים 120 בתים בכל פעם, זה כשישים בתים לשנייה — **בערך חצי אחוז מהקו.**
אודיו גדול מהקו פי עשרת אלפים. טקסט קטן ממנו פי אלף. אלו לא אותה שאלה.

#### הבעיה: לארבעה בתים אין כותרת

ההודעה הקיימת היא ארבעה בתים קבועים בלי סימן התחלה. אי אפשר פשוט "להאריך" אותה —
המקבל לא ידע איפה היא נגמרת. **הפתרון: בית פתיחה `0xAA`**, שלעולם אינו `bedId`
חוקי (המזהים הם 1, 2, 8, 9). המקבל קורא בית אחד ויודע מיד באיזה סוג הודעה מדובר:
`0xAA` ⇒ מסגרת מורחבת, כל דבר אחר ⇒ ארבעה בתים כרגיל. **הפרוטוקול הישן לא משתנה
באף בית.**

#### המסגרת המורחבת

| שדה | גודל | תוכן |
|---|---|---|
| `START` | 1 | `0xAA` |
| `DST` | 1 | יעד; `0` = לכולם |
| `SRC` | 1 | שולח (`9` = צומת האודיו) |
| `TYPE` | 1 | סוג המטען |
| `LEN` | 1 | אורך המטען, 0 עד 200 |
| `PAYLOAD` | `LEN` | טקסט `UTF-8` |
| `CRC` | 1 | `CRC-8` על `DST` עד סוף המטען |

תקורה: שישה בתים. מסגרת מלאה במקרה הגרוע — 206 בתים, **כ-18 מילי־שניות על הקו.**

**סוגי מטען:**

| `TYPE` | שם | תוכן |
|---|---|---|
| `0x01` | `NOW_PLAYING` | שם התחנה, בית אפס, כותרת השיר |
| `0x02` | `STATION` | בית אינדקס + שם התחנה — **סוגר את אי-ההתאמה בין הפאנל לצומת** |
| `0x03` | `STATUS` | מנגן/עצור, עוצמה, קצב סיביות |

#### מי מדבר ומתי — הכלל של הקו נשמר

`panel_shemi` הוא ה-bus arbiter. **צומת האודיו לא פותח פה מיוזמתו, אף פעם.**
הוא צובר את המידע ומחכה שישאלו.

- **שאלה:** ארבעה בתים `{9, 26, 0, gen}` = `RADIO_POLL`. `value` הוא מספר הדור
  האחרון שהפאנל ראה.
- **תשובה כשאין חדש:** ארבעה בתים `{9, 27, 0, gen}` = `RADIO_NOCHANGE`.
  **ארבעה בתים, לא מאתיים** — וזה המצב ברוב הפעמים.
- **תשובה כשיש חדש:** מסגרת מורחבת מסוג `0x01`.

**מתי שואלים:** רק כשהרדיו מנגן או כשמסך הרדיו פתוח, כל שתי שניות.
בשאר הזמן הקו שקט לגמרי.

#### עירה מקבלת את זה בלי בקשה

הקו הוא multi-drop — **כולם שומעים הכול.** `panel_ira` פשוט קורא מסגרות עם
`DST` אפס ומצייר אותן. **אפס תעבורה נוספת ואפס לוגיקת שכפול בין הפאנלים.**
זה בדיוק אותו יתרון שכבר קיים בהעברת השעון.

#### מאיפה הטקסט מגיע בצומת

ספריית האודיו כבר מוסרת את זה בקריאות חוזרות: `audio_showstation()` שם התחנה,
`audio_showstreamtitle()` כותרת `ICY` (בדרך כלל "אמן - שיר"), `audio_bitrate()`,
`audio_info()`. הצומת שומר את האחרון, מקדם את מונה הדור, **ומחכה.**

#### ⚠️ מה שחייב אימות על חומרה — הקידוד

**מטא-דאטה של `ICY` אינה בהכרח `UTF-8`.** תחנות שונות שולחות `UTF-8`,
`Windows-1255` או `Latin-1`, ואין דרך לדעת מראש מי שולחת מה. **לא לנחש.**
הצעד הראשון בבנייה: להדפיס את הבתים הגולמיים ב-hex לטרמינל לכל תחנה, ורק אז
להחליט — המרה לפי תחנה, או זיהוי אוטומטי.

**כיסוי הפונט:** כותרת בעברית תלויה בכיסוי של `font_hebrew.h`. תווים לטיניים
עם סימני ניקוד וגרשיים מסולסלים נופלים מחוץ לכיסוי — **להחליף תו לא מוכר ברווח**,
לא להשאיר ריבוע ולא להתרסק.

**אורך:** הקיצוץ ל-200 בתים נעשה **בצומת**, לא בפאנל. בפאנל כותרת ארוכה גוללת
(`LV_LABEL_LONG_SCROLL_CIRC`), והגלילה נעצרת כשה-screensaver פעיל — מאותה סיבה
שבגללה `lv_timer_handler` לא נקרא שם.

#### סטטוס

**תכנון בלבד.** חומרת ה-`RS-485` טרם הגיעה, המסגרת המורחבת מעולם לא נשלחה,
וכלום מזה לא רץ. אין שורת קוד אחת.

---

## 12. חשמל, `EMI` וכבלים — הוחלט

**ספק 12 וולט תעשייתי אחד, 9 עד 10 אמפר, לכל המערכת.** מפיצים 12 וולט, יורדים
ל-5 **מקומית** בכל קופסה. **חיווט כוכב** בבורגי הספק.

**נתיכים איטיים:** `F1` ראשי 8A, `F2` מנועים 6A, `F3` לוגיקה 1A.
**קבל 1000 מיקרופאראד** על כניסת ה-12 וולט של כל `בקר`. **מתג ניתוק פיזי** נגיש
מהמיטה הוא ההגנה האמיתית.

**`EMI`, לפי סדר יעילות:** קבל `0.01µF` על מגעי כל מנוע, מולחם **במנוע**; פיתול
זוג המנוע; טבעת פריט על **שני** החוטים. **מארז נחושת נדחה** — הקרינה מהחוטים.

**כבלים:** `CAT6`, **זוגות שלמים** — כתום ל-12+, ירוק ל-12−, כחול `TX`+מסה, חום
`RX`+מסה. **לעולם לא לפצל זוג. להימנע מ-`RJ45`** — 12V בשקע רשת שורף מחשבים.

---

## 13. החלטות עם עירה

- **עירה רוצה מסאז׳** ← בד־בוקס שני. **פאנל משלה** ← `Waveshare`.
- **אישרה מיקרופונים לנחירות בלבד**, כולל ייחוס לצד.
- **ארבעה סליידרים ולא שישה** — אזור, לא מנוע.
- **תמונת פתיחה אישית לכל פאנל.** `PANEL_ID` היא השורה היחידה שמשתנה.
- **מסך הבית זהה בשני הפאנלים** — הם מחליפים צדדים. פרט אחד שונה: לפאנל של עירה
  **אין** פקדי כוונון שעה/תאריך (מקבלת שעה מ-`panel_shemi` בקו).

---

## 14. מה שממתין

**חומרה בדרך:** מודולי `RS-485`, מנועים חדשים, מנתח לוגי, מודולי 433/315 מגה־הרץ.
`transceiver RS-485` ל-`panel_shemi`. `QuinLED` ל-`bedbox_ira`.

**סטטוס קושחה נוכחי:** `panel_shemi` `TEST 085` · `panel_ira` `TEST 079` ·
`bedbox_shemi` `TEST 012` · **`audionode` `TEST 014` — נמסר, טרם נבנה. `TEST 010`
הוא האחרון שאושר על חומרה ומנגן רדיו** · `bedbox_ira` טרם נכתב · `listener` טרם נכתב.

**החומרה של צומת האודיו ביד:** `ESP32-S3-WROOM-1 N16R8`, `W5500`, `PCM5102A`,
`INMP441` — ראה סעיף 8.

**עדיין לקנות:**
- **מודול `microSD` 3.3 וולט בלבד, בלי מייצב ובלי ממיר רמות** (לצומת ההקשבה) —
  ראה סעיף 9 להסבר על שני הסוגים. לקנות כמה. כרטיס 8–16 ג'יגה־בייט `Class 10`.
- מודול `A7105` (לשלט המיטה)
- כבל `Cat6` נחושת מלאה

**לכתוב:** `listener` מאפס (**הצעד הבא — העלאת המיקרופונים**), `bedbox_ira` מאפס,
פרוטוקול הקו בצד צומת האודיו **כולל המסגרת המורחבת של Rev 17** (סעיף 11),
מסך רדיו בפאנלים **עם שורת "מה מתנגן" שמוזנת מהקו, בשני הפאנלים**.

**הצעדים המיידיים לפי סדר:**
1. לבנות ולצרוב `TEST 014` **בכבל**. לוודא שלוש שורות חדשות אחרי קבלת כתובת:
   `OTA` מוכן, פורט הלוג, ורשימת התחנות.
2. לבדוק `OTA`, את `/log` ואת פורט 2323.
3. **להחזיר `placeholder` לסיסמת ה-`WiFi` ולוודא `USE_WIFI 0`**, ואז `commit`
   ו-`push` של `TEST 010`→`014` ושל המסמך הזה.
4. לצוד את ארבע התחנות החסרות (ויסקי בלוז, מפלים/טבע, מדיטציה, פינק פלויד)
   ולשמור כ-`presets`.
5. למשוך כבל `Cat6` חדש לחדר השינה. **נחושת מלאה, לא נחושת מצופה אלומיניום.**
   למשוך שני מקטעים בזמן שהחוט בקיר.
6. לשריין את `12:C1:9F:CD:37:C9` בנתב.
7. לאמת את מספרי הפינים של ה-`RS-485` ב-`panel_ira` מול הסכמה של `Waveshare`.

**`OTA` — מוצדק עכשיו.** הצומת עובד, ולכן כבל ה-`USB` הפך למטרד ולא לחבל הצלה.
טבלת המחיצות `default_16MB.csv` כבר תומכת בזה (שתי מחיצות אפליקציה). להוסיף
שם מארח וסיסמה כדי שאף אחד אחר ברשת לא יוכל לצרוב.

**הוראה מפורשת של שמי (14 באוגוסט):** קושחת צומת האודיו נכתבת **מאפס**, לא
מועתקת מ-`TEST 004`. הבנייה הראשונה על ה-`ESP32-CAM` עלתה לילה שלם והוא לא רוצה
לחזור על זה.

**הוראה מפורשת נוספת:** **ארכיטקטורה לפני בנייה.** ארבע המשימות — רדיו, `Spotify`,
צומת ההקשבה, וזיהוי עברית — צריכות להיות מובנות והקשר ביניהן סגור **לפני**
מיפוי פינים וקוד. (עודכן: האתרנט נבנה בכל זאת, כי הוא היה נדרש בכל תרחיש
ארכיטקטוני, והיה הסיכון הגדול ביותר.)

**לבנות בחומרה:** נתיכים, מתג ראשי, קבלים, זרוע החיישן, חלון ל-`BH1750`.

---

## 15. תכנון שסוכם וטרם נבנה

### `TEST 011` — דף רשת בצומת האודיו (השלב הבא, לא תלוי בשום חומרה חדשה)

שמי שאל אם אפשר לחפש מוזיקה מהטלפון, להשאיר את הטלפון מחוץ לחדר, ושהמוזיקה
תתנגן בחדר השינה. **התשובה כן, והיא מתאימה בדיוק לעקרונות הפרויקט.**

פותחים בדפדפן הטלפון את `192.168.1.195`, מקבלים דף עם תיבת חיפוש, מקישים על
תוצאה — והחדר מתחיל לנגן. **הטלפון לא מזרים את האודיו**, הוא רק שולח פקודה קצרה.
המוזיקה מגיעה מהאינטרנט ישירות לצומת הקווי. אפשר להניח את הטלפון וללכת.

זה שונה מהותית מ-`Bluetooth` או `AirPlay`, שבהם הטלפון הוא המקור וחייב להישאר
בטווח — ומחזירים `RF` לכיוון המיטה. כאן לא.

**מה שצריך לבדוק:** הטלפון על אלחוטי והצומת על כבל. שניהם על אותו נתב, אז הם
אמורים לראות זה את זה. יש נתבים שמבודדים לקוחות אלחוטיים מקוויים — אם זה דלוק,
זו הגדרה לכבות, לא תכנון מחדש.

**מה שהדף לא יכסה:** פלייליסטים אישיים ב-`Spotify`. זה עדיין דורש את מחשב
הלינוקס. רדיו ו-`Spotify` נשארות שתי בעיות נפרדות.

**ולמה זה לא עוקף:** אותו דף הופך להיות הדרך לנהל presets לתמיד, והפאנל אחר כך
רק מציג את מה ששמרת בו ושולח מספר בקו. הפאנל לעולם לא מחפש.

**דפדפן על הפאנל — לא אפשרי.** הפאנל הוא מיקרובקר עם מאות קילו־בייטים של זיכרון
עבודה. דפדפן מודרני דורש מנוע `HTML`, מנוע `JavaScript`, `TLS` ומחולל פונטים.
בנוסף הפאנל בכלל לא מחובר לרשת — רק צומת האודיו קווי.

---

**תלוי ב-`RS-485` + `listener` + `audionode` (אף אחד לא נבנה):**

- **Dreamsaver:** שני אריחים חדשים בשני הפאנלים — הקלטת חלום (החזקה) והשמעה
  (אחרי 07:00). ה-UI שולח פקודה בקו; ההקלטה על ה-`listener`; ההשמעה דרך
  ה-`audionode`. **ה-UI של המקליט כבר קיים ב-screensaver כ-stub טורי.**
- **יומן שינה:** לא אודיו — **מספרים** (אנרגיה בפס 100–600 הרץ). לתעד שלושה
  שבועות לפני שהמיטה זזה.
- **"מצב חדר שינה":** נחירה מזוהה ← הראש עולה. פעם אחת בלילה, זווית קטנה.
  בקר המיטה `CBG4-X1-3-0`: **מחזור עבודה 10%** — חייב אכיפה בתוכנה.
  **המחקר המלא על נחירות, דום נשימה, ובקרת המיקום — בסעיף 9א.**
- **התעוררות מדורגת:** מסך, רטט קל, חזק יותר, ורק בסוף צליל.
- **Spotify:** רק דרך `cspot`/`euphonium` (Spotify Connect, `Premium`, ניסיוני).

**שלטים שנחקרו:**
- מאוורר Westinghouse `SQ19D-F20`: רדיו (433 או 315 — טרם ידוע). צריך מקלט
  סופר־הטרודין.
- שלט מיטה `TXG-9-3`: **2.4 גיגה־הרץ, שבב `AMICCOM A7105`** — לא 433.
- אור ותריסים: 433, `FS1000A` בצומת האודיו, קידוד 1527.

---

## 16. לקחים — שולם עליהם בזמן

**מלכודת החלפת הקבצים — קרתה שלוש פעמים (16 באוגוסט, פעם רביעית).**
`main.cpp` ו-`platformio.ini` נגררים זה למקומו של זה, והתוצאה היא עשרות שגיאות
הידור חסרות פשר ("`TEST` does not name a type" על שורת באנר).
**לבדוק את השורה הראשונה לפני כל בנייה:**
`main.cpp` מתחיל ב-`/* ===` · `platformio.ini` מתחיל ב-`; ===`.
**מה שיעצור את זה:** לנקות עותקים ישנים מתיקיית ההורדות לפני כל זוג קבצים חדש,
או להוריד קובץ אחד בכל פעם ולאשר אותו לפני הבא.

**להצהיר פונקציה לפני שמשתמשים בה (16 באוגוסט).** `C++` קורא מלמעלה למטה.
`pollLogServer` קרא ל-`handleLine` שהוגדר מתחתיו — שגיאה אמיתית שלי.
הצהרה מקדימה אחת פתרה. **בקוד ארוך בקובץ אחד, זה יחזור.**

**"סיווג" ו"זיהוי" הם לא אותו דבר (16 באוגוסט).** ההנחה שעברית חסומה הייתה
נכונה לתמלול ושגויה לזיהוי מילות מפתח. **לפני שסוגרים כיוון בגלל שפה — לשאול
אם המודל בכלל צריך לדעת מה השפה.**

**בדיקת חשבון לפני שבוחרים פתרון (16 באוגוסט).** ההמלצה ל-`SD_MMC` הייתה זהירה
מדי; חישוב פשוט (32 קילו־בייט לשנייה) הראה ש-`SPI` מספיק בגדול. **מספר אחד
חסך פינים, קוד וזמן.**

**בדיקת צליל לפני שמאשימים את הקוד (15 באוגוסט, עלה ערב שלם):**
כשהלוג מראה שהכל מנגן ואין קול — לבנות בנייה שמסירה את הרשת ואת ספריית האודיו
ומייצרת צליל בקוד ישירות אל ה-`I2S`. אם הצליל נשמע — החומרה תקינה והבעיה בתוכנה.
אם לא — התוכנה יצאה מהמשוואה. **חצי שעה של בנייה חוסכת ערב של ניחושים.**
במקרה שלנו: הצליל לא נשמע, ואז החלפת קופסת הממיר פתרה הכל.

**חשד לרכיב פסיבי כשכל השאר מוכח.** "מבחן האצבע" בקופסת הממיר נתן זמזום, ולחיצת
`reset` נתנה קליק בסאונדבר — שניהם נראו כאילו הם מוכיחים שהקופסה עובדת. **הם לא.**
הם הוכיחו רק שהחיווט מוליך. קופסה יכולה להעביר טרנזיאנט ולא לדגום אודיו רציף.

**הקוד לא מנגן לבד אם לא אמרת לו.** `TEST 007` חיכה לפקודה בטורי. ברגע שהלוח עבר
להזנת המיטה בלי `USB`, הוא עלה, קיבל כתובת, וישב בשקט לנצח. **מכשיר בחדר שינה
חייב לנגן בלי מחשב מחובר** — מאז `TEST 008` יש `autoplay` אוטומטי.

**קבצים שמתחלפים בהורדה.** `main.cpp` ו-`platformio.ini` הוחלפו זה בזה בגרירה,
והתוצאה הייתה 41 שגיאות הידור חסרות פשר. **לבדוק את השורה הראשונה לפני בנייה:**
`main.cpp` מתחיל ב-`/* ===`, ו-`platformio.ini` מתחיל ב-`; ===`.

**מהסשן האחרון (ה-screensaver של עירה) — היקרים ביותר:**

- **ה-screensaver לא צריך להיות מסך LVGL.** ציור `gfx` גולמי מעל מסך שחור +
  דגל `bool` פשוט = אין חפיפה ואין היתקעות. מסך LVGL עם כפתור מסך-מלא = ימים
  אבודים.
- **כשה-saver הגולמי פעיל, אסור לקרוא ל-`lv_timer_handler`.** אחרת מסך שמתרענן
  על טיימר (`About`) מצייר את עצמו מעל ה-saver.
- **`bootReport()` כל 20 שניות נראה כמו reboot אבל אינו.** אין `ESP-ROM`, ה-heap
  יציב = המערכת חיה. לא לפרש הדפסה חוזרת כאתחול.
- **שני קוראי מגע מתחרים על אותו `GT911` = בעיה.** קורא אחד "גונב" את המגע מהשני
  (מנקה את הדגל). קורא אחד בלבד בכל רגע.
- **פונט `FreeSansBold24pt7b` לא קיים בהתקנת ה-`GFX` הזו.** `#include "Fonts/..."`
  נכשל. הפונט המובנה תמיד זמין.

**קודמים, עדיין תקפים:**
- **`LV_TICK_CUSTOM=1` חובה.** בלעדיו LVGL לא מצייר לעולם (~20 בניות אבודות).
- **קונפיגורציית `GT911`: מקסימום 5 נקודות מגע** (לא 10). ערך לא חוקי גורם
  `ready=1, points=0` לנצח.
- **חוצץ ה-`Wire` הוא 128 בתים וחותך בשקט.** לכתוב במנות.
- **`bb_captouch` לא מתאימה** — מבלבלת בין `CH422G` ל-FocalTech.
- **`repeated START` הכרחי לקריאת `GT911`** — `endTransmission(false)`.
- **`qio_opi` (לא `opi_opi`)** — פלאש quad, `PSRAM` אוקטלי.
- **לעולם לא לצייר ישירות מעל LVGL על מסך `RGB`** — שני מנועים נלחמים = ריצוד.
- **ידוע־טוב מנצח מסקנה.** להעתיק קוד עובד, לא להסיק מדף נתונים.
- **סדר בתים בתמונות: `little endian`.** `draw16bitRGBBitmap` ל-LITTLE,
  `draw16bitBeRGBBitmap` ל-BIG.
- **ליבה 3.x הסירה `ledcSetup`/`ledcAttachPin`.**
- **קבצים מצ׳אט נמחקים.** מה שנמסר עולה לריפו באותו יום.
- **`i2cLock` עם `portMAX_DELAY`** — לא לתחום בזמן; timeout שבר את ניקוי דגל
  ה-`GT911`.

---

## 17. המזרן — סיכון שנסגר

**נסגר.** שמי ישן לילה שלם על המערכת והרגיש מצוין.

---

*סוף המסמך — גרסה 18.*

</div>

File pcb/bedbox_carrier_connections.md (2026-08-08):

# Bg_Bed - bed box carrier board, rev A

## Connection table

| Part | Pin | Net | What it is |
|---|---|---|---|
| J1 | 1 | +12V_IN | 12 V in from the supply, before the fuse |
| J1 | 2 | GND | THE star point. Every ground in the box lands here. |
| F1 | 1 / 2 | +12V_IN / +12V | 6 A slow blade fuse |
| C1 | 1 / 2 | +12V / GND | 1000uF 25V, close to J4 |
| J4 | 1 / 2 | +12V / GND | 12 V out to the three L298N modules |
| U1 | 1 / 2 | +12V / GND | buck module, input |
| U1 | 3 / 4 | +5V / GND | buck module, output |
| U2 | 1 / 2 | +5V / GND | ESP32-S3 left socket, power |
| U2 | 5,6,7,8 | PWM1..PWM4 | GPIO4, 5, 6, 7 |
| U2 | 10 / 11 | RS485_TX / RS485_RX | GPIO8 / GPIO9 |
| U3 | 1 / 2 | GND / SPARE_3V3 | right socket, ground and 3V3 |
| U3 | 5,6,7,8 | PWM5..PWM8 | GPIO15, 16, 17, 18 |
| U3 | 12 | LED_DATA_3V3 | GPIO21, to the level shifter |
| U3 | 15..20 | SPARE1..SPARE6 | GPIO38-42, 47 |
| U5 | 1 / 2 | +5V / GND | RS-485 auto module, power |
| U5 | 3 / 4 | RS485_TX / RS485_RX | module signal side |
| J2 | 1 / 2 / 3 | RS485_A / RS485_B / GND | screw terminal to the house bus |
| J3 | 1..8 | PWM1..PWM8 | IDC to the L298N ENA / ENB inputs |
| J3 | 9 / 10 | GND / GND | two grounds in the same flat cable |
| U4 | 1 / 7 | U4_OE / GND | 74AHCT125 output enable tied low |
| U4 | 2 / 3 | LED_DATA_3V3 / LED_DATA_5V | one gate: 3V3 in, 5 V out |
| U4 | 14 | +5V | supply |
| J11  | 1 / 2 / 3 | +12V / LED_DATA_5V / GND | WS2815 strip |
| J12  | 1..6 | SPARE1..SPARE6 | spare GPIO header |
| J12  | 7 / 8 | SPARE_3V3 / GND | so a sensor can be powered from it |

## Notes

- The three L298N modules are NOT on this board. They take 12 V and GND
  straight from J4 and receive only PWM through J3.
- Their ENA / ENB factory jumpers still have to come off by hand.
- J1 pin 2 is the single star point. Do not create a second ground path.
- Eight channels so one board serves both beds: Shemi wires 8, Ira wires 6.
- GPIO numbers above are the PLAN. Check each socket hole against the board
  in your hand before the layout is finished - stock symbols get this wrong.

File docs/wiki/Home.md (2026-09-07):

# BG Bed Project Wiki

Smart wired bed / bedroom system — design, development, testing, lessons learned and build guide.

## Purpose
This wiki is written during development. It is both the project's technical source of truth and the foundation for a future public build guide / book.

## Current snapshot — 7 Sep 2026
- Two 7-inch Waveshare ESP32-S3 touch panels are in use.
- Shemi panel has the DS3231 RTC and sends time over RS-485.
- Ira panel receives the time and returns ACK.
- Shemi BedBox uses QuinLED ESP32 (WROOM-32E).
- Shemi BedBox RS-485 reception/parser has been proven on real hardware.
- 7 diagnostic NeoPixels are installed.
- TEST022 proved the pixels are RGBW (32-bit), not RGB (24-bit).
- TEST023 restores the full BedBox system with RGBW LED diagnostics.
- Massage architecture is being expanded from 6 toward 8 independently PWM-controlled motors using four L298N controllers.

## Contents
- [System Architecture](System-Architecture.md)
- [Hardware](Hardware.md)
- [Pin Assignments](Pin-Assignments.md)
- [RS-485 Protocol](RS485-Protocol.md)
- [Massage System](Massage-System.md)
- [Test Log](Test-Log.md)
- [Lessons Learned](Lessons-Learned.md)
- [Build Guide / Book Plan](Build-Guide.md)

## Status language
**PROVEN** = observed on real hardware.  
**CURRENT** = current configuration.  
**PLANNED** = proposed/future.  
**HISTORICAL** = older configuration retained for learning.

Existing `Handout.md` and `WIRING.md` remain source/history documents. Older hardware details must not override newer hardware-proven facts.

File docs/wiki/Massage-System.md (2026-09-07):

# Massage System

## Existing proven history
Shemi has already used/slept with the six-motor arrangement.

The existing firmware maps six motor PWM outputs to:
`13, 14, 18, 19, 21, 22`

## Expansion direction
The architecture is now intended to support up to 8 independently PWM-controlled vibration motors.

Hardware concept:
- 4 x L298N controllers
- 2 motors per controller
- motor polarity/direction fixed by wiring
- one PWM control signal per motor

This means the target is 8 PWM GPIOs.

## Next engineering task
Choose two additional safe PWM GPIOs on the QuinLED board after reconciling current reservations and the now-used GPIO23 RGBW diagnostic output.

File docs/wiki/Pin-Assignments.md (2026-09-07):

# Pin Assignments

## Shemi BedBox — current known assignments

| Function | GPIO | Status |
|---|---:|---|
| RS-485 RX | 16 | proven reception |
| RS-485 TX | 17 | current |
| NeoPixel RGBW DATA | 23 | proven in TEST022 through external level shifter |
| Motor PWM 1 | 13 | existing 6-motor firmware |
| Motor PWM 2 | 14 | existing 6-motor firmware |
| Motor PWM 3 | 18 | existing 6-motor firmware |
| Motor PWM 4 | 19 | existing 6-motor firmware |
| Motor PWM 5 | 21 | existing 6-motor firmware |
| Motor PWM 6 | 22 | existing 6-motor firmware |

## 8-motor expansion
Two additional PWM-capable GPIO assignments still need to be selected and hardware-tested. Do not permanently wire them until the QuinLED pin use and all existing reservations are rechecked.

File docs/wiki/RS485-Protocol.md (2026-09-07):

# RS-485 Protocol

## Hardware-proven temporary A5 frame
Current panel time/ACK traffic observed by Shemi BedBox uses 14 bytes:

`A5 SRC DST TYPE SEQ_LO SEQ_HI P0 P1 P2 P3 P4 P5 P6 XOR`

Checksum is XOR of bytes 0 through 12.

### Types observed
- `0x10` — TIME
- `0x11` — ACK

### Example TIME
`A5 01 02 10 E1 05 EA 07 09 06 17 0F 13 BB`

### Example ACK
`A5 02 01 11 E1 05 00 00 00 00 00 00 00 53`

The matching sequence number connects the TIME and ACK pair.

## Important
Motor-command framing has not yet been mapped from live panel traffic. Do not invent it. Capture real frames first.

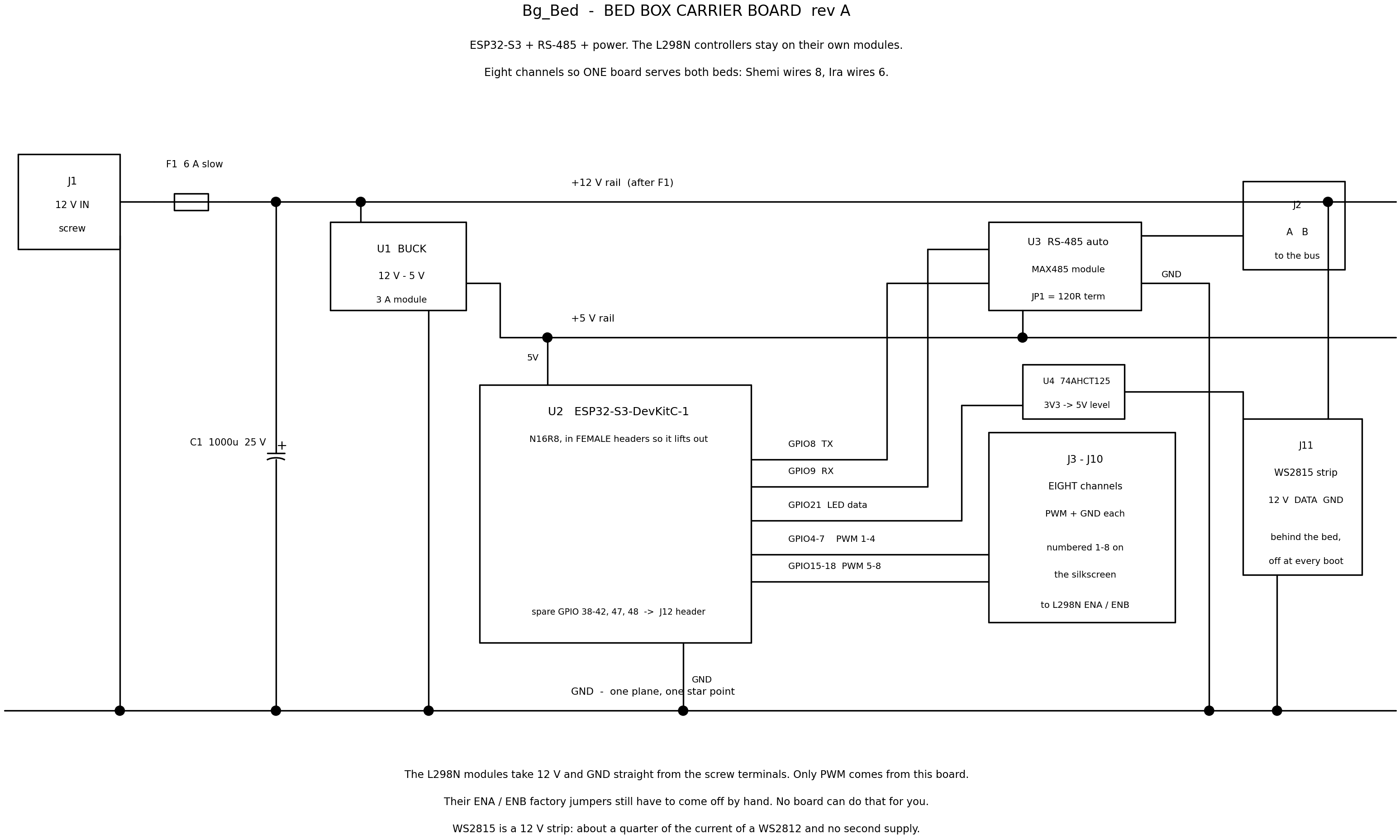
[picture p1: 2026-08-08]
pcb/bedbox_carrier_revA.png

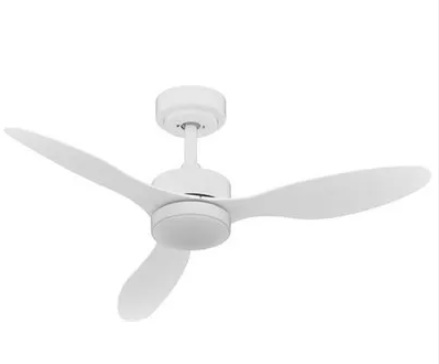
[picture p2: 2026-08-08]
panel_shemi/include/fan photo.jpg

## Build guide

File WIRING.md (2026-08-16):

# Bg_Bed — Full Interconnect Specification

**Revision 1 — 16 Aug 2026**
Companion document to `Handout.md`. This file covers **every physical wire between every module**.
Repo location: **root folder**, alongside `Handout.md`.

---

## 0. How to read this document

Each cable has its own numbered section with a pin-to-pin table.
Every row is one physical conductor.

Status marks used throughout:

| Mark | Meaning |
|---|---|
| ✅ | Confirmed on real hardware |
| 🔷 | Taken from an existing working build, not yet used for this purpose |
| ⚠️ | Proposal only — never flashed, never measured |

**Nothing marked ⚠️ should be soldered permanently before `TEST 001` runs.**

---

## 1. Module inventory

| id | Module | Board | Location | Status |
|---|---|---|---|---|
| 1 | `bedbox_shemi` | `QuinLED-ESP32` | under-bed storage | ✅ `TEST 012` running |
| 2 | `bedbox_ira` | `ESP32-S3-DevKitC-1 N16R8` | under-bed storage | ⚠️ board not arrived, no firmware |
| 8 | `listener` | `ESP32-S3-DevKitC-1 N16R8` | under-bed storage | ⚠️ hardware in hand, zero firmware |
| 9 | `audionode` | `ESP32-S3-WROOM-1 N16R8` | under-bed storage | ✅ `TEST 010` plays radio |
| — | `panel_shemi` | `ESP32-8048S043` | left headboard | ✅ `TEST 085` installed |
| — | `panel_ira` | `Waveshare ESP32-S3-Touch-LCD-4.3` | right headboard | ✅ `TEST 079` installed |

**All four boards with an id live together in the under-bed storage.**
The two panels are at the headboards. The 12V star point is in the storage space.

---

## 2. Cable schedule and estimated lengths

⚠️ **Every length below is an estimate made without measuring the room.**
Replace each one with a real tape-measure figure before buying cable. Add 20% for routing slack.

| # | Cable | From | To | Type | Est. length |
|---|---|---|---|---|---|
| C1 | Panel feed Shemi | star point | `panel_shemi` | shielded Cat6 | 200 cm |
| C2 | Panel feed Ira | star point | `panel_ira` | shielded Cat6 | 320 cm |
| C3 | Mic arm left | `listener` | mic at Shemi's pillow | shielded 4-core + drain | 220 cm |
| C4 | Mic arm right | `listener` | mic at Ira's pillow | shielded 4-core + drain | 300 cm |
| C5 | Bus jumper 1 | `bedbox_shemi` | `listener` | 3-core loose | 25 cm |
| C6 | Bus jumper 2 | `listener` | `audionode` | 3-core loose | 25 cm |
| C7 | Bus jumper 3 | `audionode` | `bedbox_ira` | 3-core loose | 25 cm |
| C8 | Live audio link | `audionode` | `listener` | 4-core ribbon | 25 cm |
| C9 | Audio out | `audionode` | converter box → soundbar | shielded audio | 230 cm |
| C10 | Ethernet | router | `audionode` | ordinary Cat5e/6 patch | ~1000 cm |
| C11 | Motor loom Shemi | `bedbox_shemi` | 6 motors in mattress | 2-core per motor | 100–250 cm each |
| C12 | Motor loom Ira | `bedbox_ira` | 8 motors in mattress | 2-core per motor | 100–250 cm each |
| C13 | Mains to PSUs | wall socket | 12V supplies | mains flex | site-dependent |

---

## 3. The RS-485 chain — order and termination

The bus is **one continuous chain**. No stars, no spurs, no T-joints.

```
panel_shemi ──C1──> bedbox_shemi ──C5──> listener ──C6──> audionode ──C7──> bedbox_ira ──C2──> panel_ira
   [120R]                                                                                        [120R]
```

- **`120Ω` termination resistors go across `A` and `B` at `panel_shemi` and `panel_ira` only.**
  The four under-bed boards are middle nodes. **No resistor on any of them.**
- `panel_shemi` is the bus arbiter and the `DS3231` time source. No other node transmits unprompted.
- Every node needs `A`, `B`, **and** a ground reference conductor. Three wires, not two.

---

## 4. Transceiver — `SP3485`

All six nodes use an `SP3485` module. Its module pinout is identical everywhere:

| Module pin | Goes to |
|---|---|
| `VCC` | 3V3 of the host board — **not 5V**, the `SP3485` is a 3.3V part |
| `GND` | host `GND` |
| `RO` | host `UART RX` |
| `DI` | host `UART TX` |
| `RE` + `DE` | tied together, to one host `GPIO` (direction control) |
| `A` | bus `A` |
| `B` | bus `B` |

⚠️ **Direction control:** most `SP3485` breakout boards bring `RE` and `DE` out separately.
Bridge them and drive with a single pin: HIGH to transmit, LOW to receive.
Some boards have this bridge already fitted — **check yours with a meter before wiring.**

---

## 5. C1 — star point to `panel_shemi` (shielded Cat6, ~200 cm)

`panel_shemi` pins: `UART1 TX = IO17`, `RX = IO18` 🔷 (already defined and in use as bidirectional UART).
`IO11`, `IO12`, `IO13` are free — they were the removed microphone.

| Cat6 pair | Colour | Conductor | Star-point end | Panel end |
|---|---|---|---|---|
| 1 | orange | 12V + | PSU +12V | buck converter input + |
| 1 | orange/white | 12V − | PSU `GND` | buck converter input − |
| 2 | green | 12V + | PSU +12V (paralleled) | buck input + (paralleled) |
| 2 | green/white | 12V − | PSU `GND` (paralleled) | buck input − (paralleled) |
| 3 | blue | `RS-485 A` | first node `A` | `SP3485` `A` |
| 3 | blue/white | `RS-485 B` | first node `B` | `SP3485` `B` |
| 4 | brown | bus `GND` reference | star `GND` | panel `GND` — **connect both ends** |
| 4 | brown/white | spare | — | — |
| — | foil + drain | shield | star `GND` | **open — do not connect** |

**Panel-side connections:**

| Signal | `panel_shemi` pin | Status |
|---|---|---|
| `SP3485 RO` → | `IO18` (RX) | 🔷 |
| `SP3485 DI` ← | `IO17` (TX) | 🔷 |
| `SP3485 RE/DE` | `IO11` | ⚠️ proposal |
| `SP3485 VCC` | 3V3 | — |
| `SP3485 GND` | `GND` | — |
| `120Ω` | across `A`–`B` | — |

---

## 6. C2 — star point to `panel_ira` (shielded Cat6, ~320 cm)

Pair assignment and shield rule are **identical to C1**. Only the panel end differs.

`panel_ira` `RS-485` is documented as `GPIO15`/`GPIO16` via `SP3485`.

| Signal | `panel_ira` pin | Status |
|---|---|---|
| `SP3485 RO` → | `GPIO16` (RX) | ⚠️ **needs verification against the Waveshare schematic** |
| `SP3485 DI` ← | `GPIO15` (TX) | ⚠️ same |
| `SP3485 RE/DE` | not yet assigned | ⚠️ **open item** |
| `SP3485 VCC` | 3V3 | — |
| `120Ω` | across `A`–`B` | — |

⚠️ `panel_ira` has very few free pins. `GPIO6` is free and comes out on the `Sensor AD` connector —
that is the obvious candidate for direction control, but it was also earmarked for the
`MP3302` backlight dimming mod. **One of those two features has to give.**

---

## 7. C3 / C4 — microphone arms (shielded 4-core + drain)

Two `INMP441` breakouts, one per pillow. **Use the two square-board units** — their `L/R` marking is legible and confirmed.

Both mics share `BCK`, `WS` and `SD`. Side is set by the `L/R` pin.

| Conductor | Listener pin | Mic Shemi (left) | Mic Ira (right) | Status |
|---|---|---|---|---|
| `3V3` | 3V3 | `VDD` | `VDD` | ⚠️ |
| `GND` | `GND` | `GND` | `GND` | ⚠️ |
| `BCK` | `GPIO4` | `SCK` | `SCK` | ⚠️ |
| `WS` | `GPIO5` | `WS` | `WS` | ⚠️ |
| `SD` | `GPIO6` | `SD` | `SD` | ⚠️ |
| `L/R` | — | to `GND` at the mic | to `3V3` at the mic | ⚠️ |
| shield | `GND` at board end | **open** | **open** | — |

**Notes**

- `SD` is one wire split to both mics — each speaks only in its own half of the frame.
- `L/R` is strapped **at the mic**, not run back down the cable. Saves a conductor.
- Fit **33Ω** series resistors on `BCK` and `WS` at the listener pin.
- Fit **100nF** across `3V3`/`GND` at each mic.
- Cross motor wiring at 90°, keep ≥10 cm from any `בקר`.

> ⚠️ **This is the single biggest unknown in the whole system.**
> `I2S` over 220–300 cm is past comfortable. It may work; it may return silence or garbage.
> `TEST 001` exists specifically to answer this, and it must run on the **real cable length**
> before anything is mounted permanently.

---

## 8. C5 / C6 / C7 — bus jumpers inside the storage (3-core, ~25 cm)

These three hops are short, inside one enclosure, on one shared 12V distribution.
**They carry bus only — no power pairs, no shield.**

| Conductor | Connects |
|---|---|
| `A` | node `A` to next node `A` |
| `B` | node `B` to next node `B` |
| `GND` | node `GND` to next node `GND` |

**Node-side transceiver pins:**

| Node | TX (`DI`) | RX (`RO`) | `RE/DE` | Status |
|---|---|---|---|---|
| `bedbox_shemi` (QuinLED) | `IO17` | `IO16` | `IO5` | ⚠️ proposal — free pins, motors use 13/14/18/19/21/22, 26/27 reserved |
| `listener` | `GPIO17` | `GPIO18` | `GPIO16` | ⚠️ proposal |
| `audionode` | `GPIO17` | `GPIO18` | `GPIO16` | 🔷 reserved in the handout, never wired |
| `bedbox_ira` | `GPIO17` | `GPIO18` | `GPIO16` | ⚠️ proposal — board not arrived |

---

## 9. C8 — live audio link, `audionode` → `listener` (4-core, ~25 cm)

**The `audionode` is the clock master on this link.** It already runs `I2S0` to the `PCM5102A`;
this link uses its free `I2S1`. The `listener` slaves to the incoming clocks.

This removes the two-clock drift problem — there is only one clock domain, so no buffer
slowly filling or emptying, and nothing to resample.

| Conductor | `audionode` pin | Direction | `listener` pin | Status |
|---|---|---|---|---|
| `BCK` | `GPIO4` | → | `GPIO15` | ⚠️ |
| `WS` | `GPIO5` | → | `GPIO21` | ⚠️ |
| `DATA` | `GPIO6` | ← | `GPIO14` | ⚠️ |
| `GND` | `GND` | — | `GND` | — |

**Free pins used here are genuinely free:** `audionode` spare list is 1, 4, 5, 6, 15, 21, 38, 47, 48
(with 16/17/18 reserved for `RS-485`). Listener 14/15/21 avoid the mic pins (4/5/6),
the microSD pins (10/11/12/13) and the bus pins (16/17/18).

⚠️ **Firmware for this does not exist on either board.** The `audionode` has no logic to switch
its output between the radio decoder and an incoming stream; the `listener` has no playback path.
Run the four wires now regardless — they cost nothing today and are painful to add later.
If live passthrough proves troublesome, the same four conductors can carry a file transfer instead.

---

## 10. C9 — audio out to soundbar (~230 cm)

Unchanged from the working system. Do not modify what is proven.

`PCM5102A` analogue out → converter box → optical → soundbar.

`PCM5102A` solder bridges, **confirmed and critical**: `H1L→L`, `H2L→L`, `H3L→H`, `H4L→L`.
`H3L` low causes a hard mute with no error message.

`PCM5102A` pins ✅ hardware-confirmed: `BCK GPIO14`, `LCK GPIO2`, `DIN GPIO13`, `SCK` pad bridged to `GND`.

---

## 11. C10 — Ethernet (~1000 cm)

Ordinary patch cable, router to `audionode`. No special treatment.

`W5500` pins ✅ hardware-confirmed: `SCLK 12`, `MOSI 11`, `MISO 10`, `SCS 9`, `INT 8`, `RST 7`.

`MAC` is `12:C1:9F:CD:37:C9` — reserve a fixed address for it in the router.

---

## 12. Power distribution

**One star point in the under-bed storage.** Every ground returns there and nowhere else.

| Rail | Feeds | Notes |
|---|---|---|
| 12V high-current | `bedbox_shemi`, `bedbox_ira` | own thick pair each, fused 6A |
| 12V low-current | C1 and C2 to the two panels | Cat6 pairs, ~1A each |
| 12V low-current | `listener`, `audionode` | short local leads |

> ⚠️ **The bed boxes must never be powered through Cat6.**
> They are fused at 6A for the motors and 23 AWG cannot carry that current.
> Their Cat6 (if any) carries bus only; power comes on a separate heavy pair.

Voltage drop reference: 23 AWG ≈ 0.067 Ω/m. Over 10 m at 1A that is about 0.7V — acceptable
for a panel, nowhere near acceptable for a motor box.

---

## 13. Connectors

**Decision: `GX12` aviation connectors** at every enclosure wall.

Screw-locking, keyed, cheap, panel-mount. Rejected alternatives and why:

- **RJ45** — the `audionode` has a real `RJ45` for the `W5500`. Two identical sockets in one
  room, one of them carrying 12V, is a fault waiting to happen.
- **USB-C** — the most common connector in the house. Someone will eventually plug a phone in.
  Also friction-retained, on a bed that articulates every night.
- **RJ11/RJ12** — those plugs physically insert into `RJ45` jacks. Same failure, smaller.

Molex Micro-Fit 3.0 is fine **inside** a box where a screwdriver is needed to reach it.

---

## 14. Open items blocking a final build

1. ⚠️ **Real measured distances** — every figure in §2 is a guess.
2. ⚠️ **`panel_ira` `RE/DE` pin** — `GPIO6` collides with the backlight dimming mod. Must choose.
3. ⚠️ **`panel_ira` `RS-485` pin numbers** — verify `GPIO15`/`GPIO16` against the Waveshare schematic.
4. ⚠️ **`SP3485` module** — confirm whether `RE`/`DE` are already bridged on the boards you bought.
5. ⚠️ **`bedbox_ira` board** — not arrived, pin map unverifiable.
6. ⚠️ **microSD module** — not yet bought. Must be the bare 3.3V SPI type: no `AMS1117`, no `74LVC125`.
7. ⚠️ **`TEST 001` on the listener** — must run at full cable length before anything is mounted.

---

*End of Revision 1.*

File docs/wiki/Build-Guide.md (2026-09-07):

# BG Bed — Build Guide / Book Plan

## Working title
**BG Bed — Designing and Building a Wired Smart Massage Bed**

## Goal
A practical, illustrated guide that lets another builder reproduce the project while also understanding the engineering decisions and troubleshooting process.

## Proposed chapters
1. The idea — why build BG Bed
2. System requirements and design philosophy
3. Overall architecture
4. Touch panels
5. The wired RS-485 network
6. Shemi BedBox
7. Ira BedBox
8. Vibration massage system
9. Eight-motor PWM architecture
10. Audio system
11. Local voice control and privacy
12. Power distribution and grounding
13. Diagnostic LEDs and serviceability
14. Firmware organization
15. Communication protocol
16. Building and wiring the hardware
17. Test methodology
18. Failures, surprises and fixes
19. Final installation
20. Operating the finished bed
21. Bill of materials
22. Schematics and pin tables
23. Source code and GitHub
24. Ideas for future versions

## Visual material to collect
- progress photographs
- wiring photographs before enclosures close
- screenshots of panel UI
- controller and PCB close-ups
- RS-485 wiring
- motor placement diagrams
- serial-monitor evidence from important tests
- before/after photos of failed fixes
- final installed system

## Logo direction
Selected direction: concept **#6** from the first BG Bed logo exploration — bed + crescent/moon + flowing wave motif. This should be refined later into a clean master logo suitable for GitHub, PDF cover, panel splash screen and Instructables.

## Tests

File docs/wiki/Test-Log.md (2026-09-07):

# Test Log

## TEST015
Serial ALIVE diagnostics proved the BedBox firmware was running. RS-485 RX initially showed zero until TTL TX/RX wiring was crossed correctly.

## TEST016
**PROVEN:** Shemi BedBox received and parsed live 14-byte A5 TIME and ACK frames. Matching sequence numbers were observed. CRC/XOR errors were zero in the shown run.

## TEST017–TEST021
NeoPixel debugging. Animation timing/logic was visible, but physical colors remained wrong and only about five LEDs responded.

## TEST022
**PROVEN:** changing the pixel format from `NEO_GRB` (24-bit RGB) to `NEO_GRBW` (32-bit RGBW) fixed the LEDs. All seven responded correctly.

This is a key diagnostic lesson: 7 logical RGB pixels send 168 bits; an RGBW chain consumes 32 bits per physical pixel, so 168/32 = 5.25 physical pixels — matching the observed symptom remarkably closely.

## TEST023
Full BedBox firmware restored with:
- 7 RGBW LEDs
- GPIO23 via external level shifter
- RS-485 parser
- motor logic
- startup red x2
- green diagnostic train
- RX yellow
- TX blue

**Observed:** TIME and ACK traffic on the shared bus with CRCbad=0. When Ira panel was powered off ACK stayed zero; when it was powered on ACK traffic returned.

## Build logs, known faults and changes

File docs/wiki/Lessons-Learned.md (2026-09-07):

# Lessons Learned

## 1. Five of seven LEDs was a data-format clue
The LED fault survived wiring changes and a level shifter. The animation sequence was correct, but colors were wrong and only about five of seven pixels reacted.

Cause: the physical pixels were RGBW (32-bit) while firmware used RGB (24-bit).

The arithmetic itself was diagnostic:
`7 x 24 / 32 = 5.25`

TEST022 changed to `NEO_GRBW` and the hardware worked.

## 2. Separate software timing from electrical/data-format faults
A standalone LED-only test removed RS-485, motors and protocol processing. That showed the animation logic was not the root problem.

## 3. TTL UART crosses; RS-485 bus does not
At the TTL side:
TX -> RX and RX <- TX.

At the differential bus:
A -> A, B -> B, GND -> GND.

## 4. Do not declare a subsystem proven from a log alone
A software `Serial.write()` proves the program attempted transmission. It does not prove another physical node received it.

## 5. Keep failed tests
The failed tests explain why the final design looks the way it does. They belong in the public build story, not in the trash.

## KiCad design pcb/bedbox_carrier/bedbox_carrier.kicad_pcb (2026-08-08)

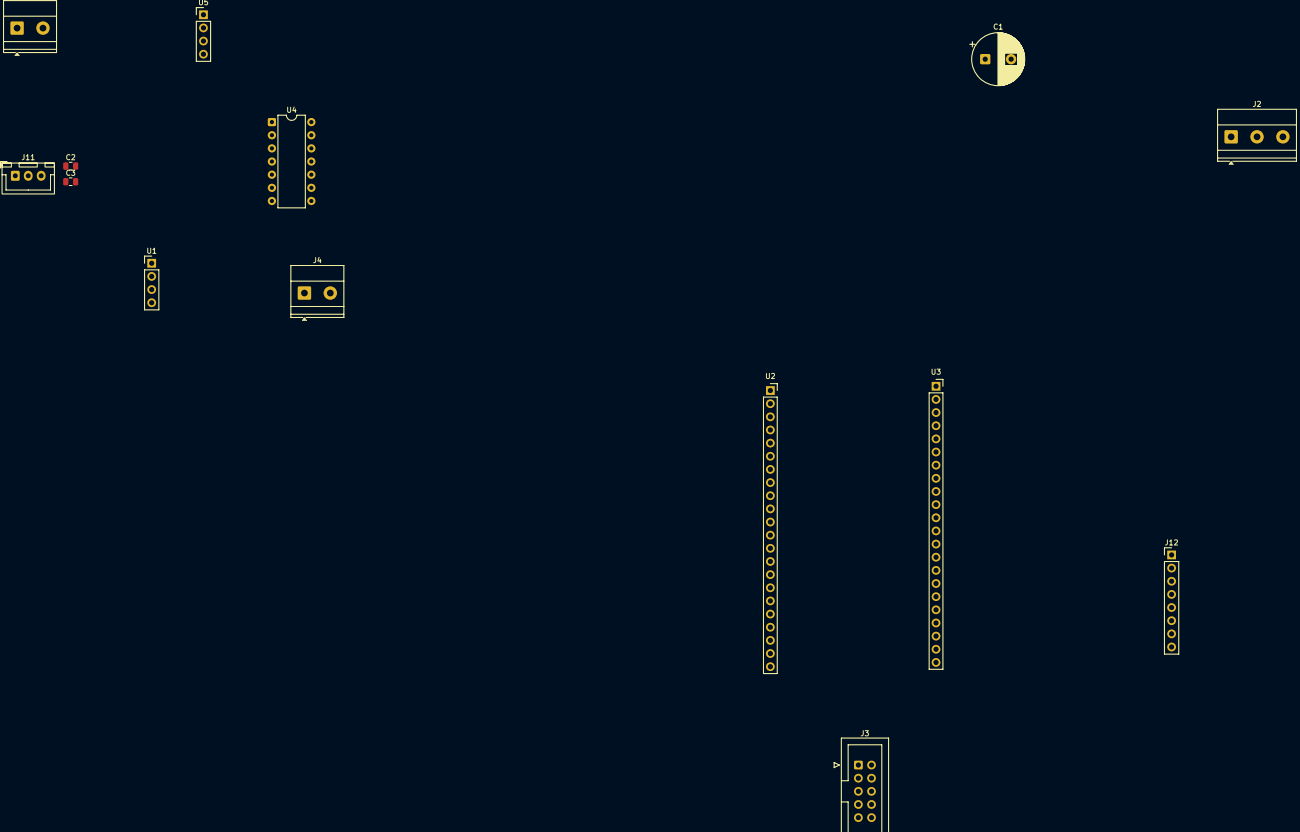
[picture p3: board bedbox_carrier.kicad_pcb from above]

Board: 2 copper layers, 14 parts (0 on the bottom side), 22 nets, no tracks yet.

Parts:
C1: 1000uF 25V; CP_Radial_D10.0mm_P5.00mm
C2, C3: 100nF; C_0805_2012Metric
J1: 12V IN; TerminalBlock_Phoenix_MKDS-1,5-2_1x02_P5.00mm_Horizontal
J2: RS485 A B GND; TerminalBlock_Phoenix_MKDS-1,5-3_1x03_P5.00mm_Horizontal
J3: PWM 1-8 IDC; IDC-Header_2x05_P2.54mm_Vertical
J4: 12V OUT to L298N; TerminalBlock_Phoenix_MKDS-1,5-2_1x02_P5.00mm_Horizontal
J11: WS2815 strip; JST_XH_B3B-XH-A_1x03_P2.50mm_Vertical
J12: SPARE GPIO; PinHeader_1x08_P2.54mm_Vertical
U1: BUCK 12V-5V 3A; PinHeader_1x04_P2.54mm_Vertical
U2: ESP32-S3 LEFT; PinSocket_1x22_P2.54mm_Vertical
U3: ESP32-S3 RIGHT; PinSocket_1x22_P2.54mm_Vertical
U4: 74AHCT125; DIP-14_W7.62mm
U5: RS485 auto module; PinHeader_1x04_P2.54mm_Vertical

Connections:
+5V: C2.1, C3.1, U1.3, U2.1, U4.14, U5.1
+12V: C1.1, J4.1, J11.1, U1.1
GND: C1.2, C2.2, C3.2, J1.2, J2.3, J3.9, J3.10, J4.2, J11.3, J12.8, U1.2, U1.4, U2.2, U3.1, U4.7, U5.2
LED_DATA_3V3: U3.12, U4.2
LED_DATA_5V: J11.2, U4.3
PWM1: J3.1, U2.5
PWM2: J3.2, U2.6
PWM3: J3.3, U2.7
PWM4: J3.4, U2.8
PWM5: J3.5, U3.5
PWM6: J3.6, U3.6
PWM7: J3.7, U3.7
PWM8: J3.8, U3.8
RS485_RX: U2.11, U5.4
RS485_TX: U2.10, U5.3
SPARE1: J12.1, U3.15
SPARE2: J12.2, U3.16
SPARE3: J12.3, U3.17
SPARE4: J12.4, U3.18
SPARE5: J12.5, U3.19
SPARE6: J12.6, U3.20
SPARE_3V3: J12.7, U3.2

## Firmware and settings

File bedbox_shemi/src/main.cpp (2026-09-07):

// ============================================================
// BED BOX SHEMI - TEST 024
// QuinLED-ESP32 (WROOM-32E) - 6 motors + RS485 + 7 RGBW NeoPixels
// ============================================================
//
// TEST 024
// - Diagnostic LED behavior redesigned for closed-loop testing.
// - Startup: ALL 7 LEDs flash RED twice.
// - Bus alive: ONE GREEN LED scans back-and-forth.
// - Bus silent for 2 seconds: ONE RED LED scans back-and-forth.
// - Valid massage command Panel -> BedBox: 3-BLUE train moves LEFT-to-RIGHT.
// - BedBox feedback -> Panel: 3-YELLOW train moves RIGHT-to-LEFT.
// - If feedback is transmitted during the blue command indication, yellow is
//   queued and starts immediately after blue, so both directions are visible.
// - A5 TIME/ACK traffic keeps the communication-alive indication green but does
//   NOT trigger the blue command train.
// - Bad A5 checksum: all 7 LEDs flash RED briefly.
// - Motor control, pattern engine, RS485 parser, GPIO mapping and RGBW format
//   are unchanged from TEST023.
// - NOT YET RUN ON HARDWARE.
//
// TEST 023
// - Full BedBox Shemi system restored after the standalone LED tests.
// - Exactly 7 physical NeoPixels.
// - IMPORTANT FIX proven by TEST022: LEDs are RGBW, so use NEO_GRBW (32-bit),
//   not NEO_GRB (24-bit).
// - NeoPixel DATA = GPIO23 through the external 3.3V -> 5V level shifter.
// - Startup: ALL 7 LEDs flash RED twice.
// - Normal: a train of 3 GREEN LEDs moves continuously right-to-left.
// - Valid received A5/14-byte frame: the SAME train turns YELLOW briefly.
// - BedBox transmission: the SAME train turns BLUE briefly.
// - Bad A5 checksum: all 7 LEDs flash RED briefly.
// - RS485 parser and motor/pattern behavior are restored from TEST018.
// - USB Serial diagnostics remain active.
//
// TEST022 proved the RGBW LED format and GPIO23+level-shifter path on hardware.
// TEST023 full-system integration is NOT proven until built/uploaded/tested.
//
// // WIRING
// NeoPixels: +5V -> 5V, GND -> GND, DIN <- HV1 of external level shifter; GPIO23 -> LV1.
// RS485 module TTL side:
//   VCC -> 5V, GND -> GND, TXD -> GPIO16, RXD -> GPIO17.
// RS485 bus side: A+ -> A, B- -> B, Earth -> common GND.
//
// ============================================================

#include <Arduino.h>
#include <Preferences.h>
#include <Adafruit_NeoPixel.h>

#define TEST_NUMBER 24

#define BOOT_SELFTEST 0

#if defined(ESP_ARDUINO_VERSION_MAJOR) && ESP_ARDUINO_VERSION_MAJOR >= 3
  #define LEDC_BY_PIN 1
#else
  #define LEDC_BY_PIN 0
#endif

// ---------------- Physical configuration ----------------
const uint8_t MY_BED_ID      = 1;
const int     NUM_MOTORS     = 6;
const int     MOTORS_PRESENT = 6;

const int MOTOR_PIN[NUM_MOTORS]  = {13, 14, 18, 19, 21, 22};
const int MOTOR_ZONE[NUM_MOTORS] = { 0,  0,  1,  2,  3,  3};
const int MOTOR_BIG[NUM_MOTORS]  = { 0,  0,  1,  1,  0,  0};

const int   NUM_ZONES = 4;
const char* ZONE_NAME[NUM_ZONES] = {"Head", "UpperBack", "LowerBack", "Legs"};

const int HEAD_L = 0, HEAD_R = 1, BACK_U = 2, BACK_L = 3, LEG_L = 4, LEG_R = 5;

// ---------------- PWM ----------------
const int PWM_FREQ = 20000;
const int PWM_RES  = 8;

int       MIN_DUTY_SMALL = 60;
int       MIN_DUTY_BIG   = 165;
const int KICK_MS        = 60;

const int TICK_MS     = 20;
const int RAMP_STEP   = 4;
const int FLOOR_LEVEL = 0;

// ---------------- UART / RS485 ----------------
const int UART_RX = 16;
const int UART_TX = 17;
const unsigned long FRAME_GAP_MS = 50;

// ---------------- NeoPixel diagnostics ----------------
const int NEO_PIN   = 23;
const int NEO_COUNT = 7;
const uint8_t NEO_BRIGHTNESS = 45;

Adafruit_NeoPixel pixels(NEO_COUNT, NEO_PIN, NEO_GRBW + NEO_KHZ800);

enum LedEvent {
  LED_EVT_NONE = 0,
  LED_EVT_COMMAND,    // Panel -> BedBox, BLUE, left-to-right
  LED_EVT_FEEDBACK,   // BedBox -> Panel, YELLOW, right-to-left
  LED_EVT_FAULT
};

LedEvent ledEvent = LED_EVT_NONE;
unsigned long ledEventUntil = 0;
unsigned long ledStepAt = 0;

// Idle scanner: exactly ONE pixel bounces between the ends.
int idlePixel = 0;
int idleDir   = +1;

// Event train head. It is reset when an event starts so direction is obvious.
int eventHead = 0;
bool feedbackPending = false;

// Communication is considered alive after any VALID received A5 or legacy frame.
// TIME/ACK therefore keep this green even when no massage command is being sent.
unsigned long lastValidCommMs = 0;
bool haveValidComm = false;

const unsigned long LED_STEP_MS       = 120;
const unsigned long COMMAND_HOLD_MS   = 520;
const unsigned long FEEDBACK_HOLD_MS  = 520;
const unsigned long FAULT_HOLD_MS     = 900;
const unsigned long COMM_TIMEOUT_MS   = 2000;

uint32_t C_RED, C_GREEN, C_YELLOW, C_BLUE, C_WHITE, C_OFF;

void noteValidCommunication() {
  haveValidComm = true;
  lastValidCommMs = millis();
}

void startLedEvent(LedEvent e, unsigned long holdMs) {
  ledEvent = e;
  ledEventUntil = millis() + holdMs;
  ledStepAt = millis();

  if (e == LED_EVT_COMMAND) {
    eventHead = 0;                 // start at left, move right
  } else if (e == LED_EVT_FEEDBACK) {
    eventHead = NEO_COUNT - 1;     // start at right, move left
  }
}

void showCommandTx() {
  // A new command should always be visible as BLUE first.
  feedbackPending = false;
  startLedEvent(LED_EVT_COMMAND, COMMAND_HOLD_MS);
}

void showFeedbackTx() {
  // A feedback report often follows the command almost immediately.
  // Queue yellow behind blue instead of overwriting blue before it can be seen.
  if (ledEvent == LED_EVT_COMMAND) {
    feedbackPending = true;
    return;
  }
  startLedEvent(LED_EVT_FEEDBACK, FEEDBACK_HOLD_MS);
}

void setFaultEvent() {
  feedbackPending = false;
  startLedEvent(LED_EVT_FAULT, FAULT_HOLD_MS);
}

void startupLedTest() {
  // Hardware-proven RGBW chain: exactly 7 physical NeoPixels.
  // All seven flash RED twice at startup.
  for (int pass = 0; pass < 2; pass++) {
    pixels.fill(C_RED);
    pixels.show();
    delay(500);

    pixels.clear();
    pixels.show();
    delay(300);
  }

  pixels.clear();
  pixels.show();
  delay(250);
}

void updateDiagnostics() {
  const unsigned long now = millis();

  // Finish a temporary event. Feedback queued during BLUE starts next.
  if (ledEvent != LED_EVT_NONE && (long)(now - ledEventUntil) >= 0) {
    if (ledEvent == LED_EVT_COMMAND && feedbackPending) {
      feedbackPending = false;
      startLedEvent(LED_EVT_FEEDBACK, FEEDBACK_HOLD_MS);
    } else {
      ledEvent = LED_EVT_NONE;
    }
  }

  // Advance animation only on its timing tick.
  if ((long)(now - ledStepAt) >= 0) {
    ledStepAt = now + LED_STEP_MS;

    if (ledEvent == LED_EVT_COMMAND) {
      eventHead++;
      if (eventHead >= NEO_COUNT) eventHead = 0;
    }
    else if (ledEvent == LED_EVT_FEEDBACK) {
      eventHead--;
      if (eventHead < 0) eventHead = NEO_COUNT - 1;
    }
    else if (ledEvent == LED_EVT_NONE) {
      idlePixel += idleDir;
      if (idlePixel >= NEO_COUNT - 1) {
        idlePixel = NEO_COUNT - 1;
        idleDir = -1;
      } else if (idlePixel <= 0) {
        idlePixel = 0;
        idleDir = +1;
      }
    }
  }

  pixels.clear();

  if (ledEvent == LED_EVT_FAULT) {
    bool on = ((now / 140) & 1) == 0;
    if (on) pixels.fill(C_RED);
    pixels.show();
    return;
  }

  if (ledEvent == LED_EVT_COMMAND) {
    // 3-pixel BLUE train, LEFT -> RIGHT.
    for (int i = 0; i < 3; i++) {
      int p = eventHead - i;
      while (p < 0) p += NEO_COUNT;
      pixels.setPixelColor(p, C_BLUE);
    }
    pixels.show();
    return;
  }

  if (ledEvent == LED_EVT_FEEDBACK) {
    // 3-pixel YELLOW train, RIGHT -> LEFT.
    for (int i = 0; i < 3; i++) {
      int p = eventHead + i;
      while (p >= NEO_COUNT) p -= NEO_COUNT;
      pixels.setPixelColor(p, C_YELLOW);
    }
    pixels.show();
    return;
  }

  // Idle: exactly ONE pixel. GREEN = recent valid communication,
  // RED = no valid communication for COMM_TIMEOUT_MS (or none since boot).
  const bool commAlive = haveValidComm && (now - lastValidCommMs <= COMM_TIMEOUT_MS);
  pixels.setPixelColor(idlePixel, commAlive ? C_GREEN : C_RED);
  pixels.show();
}

// ---------------- Protocol ----------------
enum Cmd {
  CMD_OFF = 0,
  CMD_ALL = 1,
  CMD_ZONE = 2,
  CMD_MOTOR = 3,
  CMD_PRESET = 4,
  CMD_TIMER = 5
};

const uint8_t RPT_LEVEL = 20;
const unsigned long REPORT_MS = 150;
const int REPORT_STEP = 2;

// ---------------- Patterns ----------------
enum Pattern {
  PAT_WATERFALL = 0,
  PAT_RISE      = 1,
  PAT_ROCK      = 2,
  PAT_DIAGONAL  = 3,
  PAT_SIDE      = 4,
  PAT_CIRCLE    = 5,
  PAT_KNEAD     = 6,
  PAT_PULSE     = 7,
  PAT_BREATHE   = 8,
  PAT_RAIN      = 9,
  PAT_SHUFFLE   = 10,
  PAT_COUNT     = 11
};

const char* PATTERN_NAME[PAT_COUNT] = {
  "Waterfall", "Rise", "Rock", "Diagonal", "Side", "Circle",
  "Knead", "Pulse", "Breathe", "Rain", "Shuffle"
};

// ---------------- State ----------------
int motorLevel[NUM_MOTORS];
int tgtLevel[NUM_MOTORS];

unsigned long timerEndMs = 0;
unsigned long nextTickMs = 0;
unsigned long stepAtMs   = 0;
unsigned long patStartMs = 0;

int activePreset = -1;
int presetLevel  = 60;
int phase        = 0;
bool demoActive  = false;

Preferences prefs;

int lastSentZone[NUM_ZONES];
unsigned long lastReportMs = 0;

const int A5_FRAME_LEN = 14;
uint8_t a5Frame[A5_FRAME_LEN];
int a5Len = 0;
bool collectingA5 = false;

uint8_t legacyBuf[4];
int legacyLen = 0;

unsigned long lastByteMs = 0;

uint8_t lastFrame[14] = {0};
int lastFrameLen = 0;
unsigned long lastFrameMs = 0;

long a5FramesSeen = 0;
long timeFramesSeen = 0;
long ackFramesSeen = 0;
long legacyFramesSeen = 0;
long checksumFaults = 0;
long rxBytesSeen = 0;
long txFrames = 0;

unsigned long nextAlivePrint = 0;

// ---------------- Forward declarations ----------------
int  levelToDuty(int m, int level);
void pwmWrite(int m, int duty);
void setMotor(int m, int level);
void setZone(int z, int level);
void setAll(int level);
void allOff();
void handleMessage(uint8_t bedId, uint8_t cmd, uint8_t target, uint8_t value);
void saveState();
void loadState();
void startPattern(int p, int level);
void tickEngine();
void runCalib(int m);
void printStatus();
void printLink();
void handleLine(String line);
void processA5Frame();
void processLegacyPacket();
void pollUart();
void reportLevels();
void demoSet(int m, int level);
bool demoWait(unsigned long ms);
bool demoRamp(int m, int fromL, int toL, unsigned long ms);
void runDemoPass();
void stopDemoToManual();

// ============================================================
// Low level
// ============================================================
void pwmWrite(int m, int duty) {
#if LEDC_BY_PIN
  ledcWrite(MOTOR_PIN[m], duty);
#else
  ledcWrite(m, duty);
#endif
}

int levelToDuty(int m, int level) {
  if (level <= 0) return 0;
  if (level > 100) level = 100;
  int minDuty = MOTOR_BIG[m] ? MIN_DUTY_BIG : MIN_DUTY_SMALL;
  return minDuty + (255 - minDuty) * (level - 1) / 99;
}

void setMotor(int m, int level) {
  if (m < 0 || m >= MOTORS_PRESENT) return;
  bool wasOff = (motorLevel[m] == 0);
  motorLevel[m] = constrain(level, 0, 100);
  tgtLevel[m]   = motorLevel[m];
  int duty = levelToDuty(m, motorLevel[m]);
  if (duty > 0 && wasOff && duty < 255) {
    pwmWrite(m, 255);
    delay(KICK_MS);
  }
  pwmWrite(m, duty);
}

void setZone(int z, int level) {
  for (int m = 0; m < MOTORS_PRESENT; m++)
    if (MOTOR_ZONE[m] == z) setMotor(m, level);
}

void setAll(int level) {
  for (int m = 0; m < MOTORS_PRESENT; m++) setMotor(m, level);
}

void allOff() {
  activePreset = -1;
  timerEndMs = 0;
  for (int m = 0; m < NUM_MOTORS; m++) tgtLevel[m] = 0;
  setAll(0);
}

void tgtMotor(int m, int level) {
  if (m >= 0 && m < MOTORS_PRESENT)
    tgtLevel[m] = constrain(level, 0, 100);
}

void tgtZone(int z, int level) {
  for (int m = 0; m < MOTORS_PRESENT; m++)
    if (MOTOR_ZONE[m] == z) tgtLevel[m] = constrain(level, 0, 100);
}

void tgtAll(int level) {
  for (int m = 0; m < MOTORS_PRESENT; m++)
    tgtLevel[m] = constrain(level, 0, 100);
}

// ============================================================
// Protocol
// ============================================================
void handleMessage(uint8_t bedId, uint8_t cmd, uint8_t target, uint8_t value) {
  if (bedId != MY_BED_ID && bedId != 0) return;

  switch (cmd) {
    case CMD_OFF:    allOff(); break;
    case CMD_ALL:    activePreset = -1; setAll(value); break;
    case CMD_ZONE:   activePreset = -1; setZone(target, value); break;
    case CMD_MOTOR:  activePreset = -1; setMotor(target, value); break;
    case CMD_PRESET: startPattern(target, value ? value : 60); break;
    case CMD_TIMER:  timerEndMs = millis() + (unsigned long)value * 60000UL; break;
    default: return;
  }

  saveState();
}

// ============================================================
// UART / RS485 receiver
// ============================================================
uint8_t xorChecksum(const uint8_t* data, int len) {
  uint8_t x = 0;
  for (int i = 0; i < len; i++) x ^= data[i];
  return x;
}

void processA5Frame() {
  if (a5Len != A5_FRAME_LEN) return;

  uint8_t calc = xorChecksum(a5Frame, 13);
  uint8_t got  = a5Frame[13];

  if (calc != got) {
    checksumFaults++;
    setFaultEvent();
    Serial.printf("[RS485 A5 BAD CRC] calc=%02X got=%02X :", calc, got);
    for (int i = 0; i < A5_FRAME_LEN; i++) Serial.printf(" %02X", a5Frame[i]);
    Serial.println();
    return;
  }

  a5FramesSeen++;
  memcpy(lastFrame, a5Frame, A5_FRAME_LEN);
  lastFrameLen = A5_FRAME_LEN;
  lastFrameMs = millis();

  uint8_t src  = a5Frame[1];
  uint8_t dst  = a5Frame[2];
  uint8_t type = a5Frame[3];
  uint16_t seq = (uint16_t)a5Frame[4] | ((uint16_t)a5Frame[5] << 8);

  noteValidCommunication();

  if (type == 0x10) {
    timeFramesSeen++;
    uint16_t year = (uint16_t)a5Frame[6] | ((uint16_t)a5Frame[7] << 8);
    uint8_t month  = a5Frame[8];
    uint8_t day    = a5Frame[9];
    uint8_t hour   = a5Frame[10];
    uint8_t minute = a5Frame[11];
    uint8_t second = a5Frame[12];

    Serial.printf("[RS485 A5 TIME] src=%u dst=%u seq=%u %04u-%02u-%02u %02u:%02u:%02u\n",
                  src, dst, seq, year, month, day, hour, minute, second);
  }
  else if (type == 0x11) {
    ackFramesSeen++;
    Serial.printf("[RS485 A5 ACK] src=%u dst=%u seq=%u\n",
                  src, dst, seq);
  }
  else {
    Serial.printf("[RS485 A5] src=%u dst=%u type=0x%02X seq=%u payload:",
                  src, dst, type, seq);
    for (int i = 6; i <= 12; i++) Serial.printf(" %02X", a5Frame[i]);
    Serial.println();
  }
}

void processLegacyPacket() {
  if (legacyLen != 4) return;

  legacyFramesSeen++;
  memcpy(lastFrame, legacyBuf, 4);
  lastFrameLen = 4;
  lastFrameMs = millis();

  noteValidCommunication();

  Serial.printf("[RS485 LEGACY CMD] bed=%u cmd=%u target=%u value=%u\n",
                legacyBuf[0], legacyBuf[1], legacyBuf[2], legacyBuf[3]);

  // Blue is reserved for an actual massage order addressed to this BedBox.
  if ((legacyBuf[0] == MY_BED_ID || legacyBuf[0] == 0) && legacyBuf[1] <= CMD_TIMER) {
    showCommandTx();
  }

  handleMessage(legacyBuf[0], legacyBuf[1], legacyBuf[2], legacyBuf[3]);
}

void pollUart() {
  while (Serial2.available()) {
    unsigned long now = millis();
    uint8_t b = (uint8_t)Serial2.read();

    rxBytesSeen++;

    // Quiet gap closes a pending legacy packet.
    if (!collectingA5 && legacyLen > 0 && now - lastByteMs > FRAME_GAP_MS) {
      if (legacyLen == 4) processLegacyPacket();
      else {
        Serial.printf("[RS485 RAW] ignored legacy-sized fragment len=%d\n", legacyLen);
      }
      legacyLen = 0;
    }

    lastByteMs = now;

    if (collectingA5) {
      a5Frame[a5Len++] = b;

      if (a5Len == A5_FRAME_LEN) {
        processA5Frame();
        collectingA5 = false;
        a5Len = 0;
      }
      continue;
    }

    if (b == 0xA5) {
      // A5 is a hard start marker for the observed 14-byte protocol.
      // Drop any incomplete non-A5 fragment rather than mixing protocols.
      if (legacyLen > 0) {
        Serial.printf("[RS485 RAW] dropped %d byte fragment before A5\n", legacyLen);
        legacyLen = 0;
      }

      collectingA5 = true;
      a5Len = 0;
      a5Frame[a5Len++] = b;
      continue;
    }

    // Non-A5 traffic can still be the legacy 4-byte BedBox protocol.
    if (legacyLen < 4) {
      legacyBuf[legacyLen++] = b;
    } else {
      // More than 4 non-A5 bytes without a quiet gap: not a valid legacy packet.
      Serial.println("[RS485 RAW] non-A5 stream longer than 4 bytes - discarded");
      legacyLen = 0;
    }
  }

  // Close a legacy packet only after a quiet gap.
  if (!collectingA5 && legacyLen > 0 && millis() - lastByteMs > FRAME_GAP_MS) {
    if (legacyLen == 4) processLegacyPacket();
    else Serial.printf("[RS485 RAW] ignored fragment len=%d\n", legacyLen);
    legacyLen = 0;
  }

  // A5 frame timed out before 14 bytes: clear it safely, no motor action.
  if (collectingA5 && a5Len > 0 && millis() - lastByteMs > FRAME_GAP_MS) {
    Serial.printf("[RS485 A5] incomplete frame len=%d - discarded\n", a5Len);
    collectingA5 = false;
    a5Len = 0;
  }
}

// ============================================================
// Uplink
// ============================================================
void reportLevels() {
  unsigned long now = millis();
  if (now - lastReportMs < REPORT_MS) return;
  lastReportMs = now;

  for (int z = 0; z < NUM_ZONES; z++) {
    int lvl = 0;

    for (int m = 0; m < MOTORS_PRESENT; m++)
      if (MOTOR_ZONE[m] == z && motorLevel[m] > lvl)
        lvl = motorLevel[m];

    if (abs(lvl - lastSentZone[z]) < REPORT_STEP) continue;
    lastSentZone[z] = lvl;

    uint8_t out[4] = {
      MY_BED_ID,
      RPT_LEVEL,
      (uint8_t)z,
      (uint8_t)lvl
    };

    Serial2.write(out, 4);
    Serial2.flush();
    txFrames++;
    showFeedbackTx();

    Serial.printf("[RS485 TX] bed=%u rpt=%u zone=%u level=%u\n",
                  out[0], out[1], out[2], out[3]);
  }
}

// ============================================================
// Persistence
// ============================================================
void saveState() {
  prefs.begin("bedbox", false);
  prefs.putBytes("levels", motorLevel, sizeof(motorLevel));
  prefs.putInt("preset", activePreset);
  prefs.putInt("plevel", presetLevel);
  prefs.end();
}

void loadState() {
  int saved[NUM_MOTORS];
  for (int m = 0; m < NUM_MOTORS; m++) saved[m] = 0;
  int savedPreset = -1;

  prefs.begin("bedbox", true);
  if (prefs.isKey("levels"))
    prefs.getBytes("levels", saved, sizeof(saved));
  savedPreset = prefs.getInt("preset", -1);
  presetLevel = prefs.getInt("plevel", 60);
  prefs.end();

  if (savedPreset >= 0 && savedPreset < PAT_COUNT) {
    Serial.printf("Resuming pattern %s at %d%%\n",
                  PATTERN_NAME[savedPreset], presetLevel);
    startPattern(savedPreset, presetLevel);
    return;
  }

  bool any = false;
  for (int m = 0; m < MOTORS_PRESENT; m++) {
    if (saved[m] > 0) {
      setMotor(m, saved[m]);
      any = true;
    }
  }

  if (any) Serial.println("Resuming the levels that were running at power-off.");
  else     Serial.println("Nothing to resume - starting idle.");
}

// ============================================================
// Pattern engine
// ============================================================
void startPattern(int p, int level) {
  if (p < 0 || p >= PAT_COUNT) return;
  activePreset = p;
  presetLevel  = constrain(level, 10, 100);
  phase        = 0;
  stepAtMs     = 0;
  patStartMs   = millis();
  Serial.printf("Pattern %s at %d%%\n", PATTERN_NAME[p], presetLevel);
}
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
void loop() {
  updateDiagnostics();
  printAliveHeartbeat();

  if (demoActive) {
    runDemoPass();
    return;
  }

  pollUart();

  while (Serial.available()) {
    char c = Serial.read();

    if (c == '\n' || c == '\r') {
      if (inBuf.length()) {
        handleLine(inBuf);
        inBuf = "";
      }
    } else {
      inBuf += c;
    }
  }

  if (timerEndMs && millis() > timerEndMs) {
    timerEndMs = 0;
    activePreset = -1;

    for (int m = 0; m < MOTORS_PRESENT; m++) {
      tgtLevel[m] = 0;
      setMotor(m, 0);
    }

    Serial.println("Session timer finished - motors stopped, settings kept.");
  }

  tickEngine();
  reportLevels();
}

// ============================================================
// BED BOX SHEMI - TEST 024 - end of file
// RS485 RX=16 TX=17, NeoPixel DATA=23 via external level shifter, 7 LEDs
// ============================================================

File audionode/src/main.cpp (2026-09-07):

/* ============================================================
 *                        TEST  016
 * ============================================================
 *
 *  BG BED - AUDIO NODE INTEGRATION SELF TEST
 *
 *  Board : ESP32-S3-WROOM-1 N16R8
 *
 *  Existing / already used from TEST014:
 *    W5500 Ethernet
 *      SCK  = GPIO12
 *      MOSI = GPIO11
 *      MISO = GPIO10
 *      CS   = GPIO9
 *      INT  = GPIO8
 *      RST  = GPIO7
 *
 *    PCM5102A I2S
 *      BCLK = GPIO14
 *      LRC  = GPIO2
 *      DOUT = GPIO13
 *
 *  Added in TEST016:
 *    RS485 auto-direction module
 *      ESP32 TX GPIO17 -> module RXD
 *      ESP32 RX GPIO18 <- module TXD
 *      GND common
 *
 *    7 RGBW NeoPixels
 *      DATA = GPIO21
 *      exactly 7 pixels
 *      NEO_GRBW + NEO_KHZ800
 *
 *    microSD module (3.3V)
 *      CLK  = GPIO35
 *      MISO = GPIO36
 *      MOSI = GPIO37
 *      CS   = GPIO39
 *      VCC  = 3.3V
 *      GND  = GND
 *
 *  TEST016 SERIAL RECOVERY:
 *    Forces ESP32-S3 native USB CDC serial on boot via platformio.ini.
 *    Prints an unmistakable USB SERIAL ALIVE heartbeat every 1 second.
 *    The heartbeat runs regardless of Ethernet, SD, RS485 or Audio state.
 *    This isolates terminal/USB from the rest of the AudioNode.
 *
 *  PURPOSE:
 *    One firmware to prove that Ethernet + internal network,
 *    SD card, RS485 receive/transmit path, 7 RGBW pixels and
 *    PCM5102A audio can coexist on the AudioNode.
 *
 *  LED diagnostics:
 *    startup: RED -> GREEN -> BLUE -> WHITE
 *    normal:  one GREEN pixel scans
 *    fault:   one RED pixel scans
 *    RS485 RX valid A5 frame: BLUE flash
 *    RS485 TX diagnostic frame: YELLOW flash
 *    bad A5 CRC: all RED flash
 *
 *  RS485:
 *    listens for the same 14-byte A5 frame used by the BG Bed bus:
 *      0  0xA5
 *      1  SRC
 *      2  DST
 *      3  TYPE
 *      4  SEQ low
 *      5  SEQ high
 *      6..12 payload/time fields
 *      13 XOR CRC of bytes 0..12
 *
 *    TEST016 does NOT execute audio commands from RS485 yet.
 *    It only proves transport and reports what it sees.
 *
 *  Serial commands:
 *    i = print complete diagnostics
 *    x = transmit one harmless diagnostic RS485 frame
 *    p = play test internet radio stream
 *    s = stop audio
 *
 *  Web:
 *    open http://<AudioNode-IP>/
 *    shows Ethernet / SD / RS485 / LEDs / Audio diagnostics.
 *
 *  NOT YET TESTED ON HARDWARE.
 * ============================================================ */

#define TEST_NUMBER 16

#define USE_WIFI 0

#include <Arduino.h>
#include <SPI.h>
#include <SD.h>
#include <ETH.h>
#include <WiFi.h>
#include <WebServer.h>
#include <Adafruit_NeoPixel.h>
#include "Audio.h"

/* ============================================================
 * PIN MAP
 * ============================================================ */

// W5500 - preserve TEST014 wiring
#define PIN_ETH_SCK   12
#define PIN_ETH_MOSI  11
#define PIN_ETH_MISO  10
#define PIN_ETH_CS     9
#define PIN_ETH_INT    8
#define PIN_ETH_RST    7

// PCM5102A - preserve TEST014 wiring
#define PIN_I2S_BCLK  14
#define PIN_I2S_LRC    2
#define PIN_I2S_DOUT  13

// RS485 auto-direction module
#define PIN_RS485_TX  17
#define PIN_RS485_RX  18

// exactly 7 RGBW NeoPixels
#define PIN_PIXELS    21
#define PIXEL_COUNT    7

// microSD - separate SPI bus
#define PIN_SD_SCK    35
#define PIN_SD_MISO   36
#define PIN_SD_MOSI   37
#define PIN_SD_CS     39

/* ============================================================
 * SETTINGS
 * ============================================================ */

#define ETH_PHY_ADDRESS   1
#define ETH_SPI_MHZ       12
#define RS485_BAUD        115200
#define STATUS_EVERY_MS   10000
#define LED_STEP_MS       110
#define LED_EVENT_MS      220

#define VOLUME_START      10
#define VOLUME_MAX        21

static const char *TEST_STREAM =
  "https://ice5.somafm.com/groovesalad-128-mp3";

/* ============================================================
 * OBJECTS
 * ============================================================ */

Audio audio;
WebServer server(80);

// W5500 uses global SPI.
// SD gets the second hardware SPI controller.
SPIClass sdSPI(HSPI);

Adafruit_NeoPixel pixels(
  PIXEL_COUNT,
  PIN_PIXELS,
  NEO_GRBW + NEO_KHZ800
);

/* ============================================================
 * STATE
 * ============================================================ */

static bool g_ethLink = false;
static bool g_haveIP = false;
static bool g_sdOK = false;
static bool g_sdWriteOK = false;
static bool g_audioConfigured = false;
static bool g_webStarted = false;

static uint64_t g_sdSizeMB = 0;

static uint32_t g_rs485Bytes = 0;
static uint32_t g_rs485A5Good = 0;
static uint32_t g_rs485A5Bad = 0;
static uint32_t g_rs485TxFrames = 0;
static uint32_t g_rs485OtherBytes = 0;

static uint8_t g_lastSrc = 0;
static uint8_t g_lastDst = 0;
static uint8_t g_lastType = 0;
static uint16_t g_lastSeq = 0;

static unsigned long g_bootMs = 0;
static unsigned long g_lastStatus = 0;
static unsigned long g_lastSerialHeartbeat = 0;

enum LedEvent {
  LED_EVENT_NONE,
  LED_EVENT_RX,
  LED_EVENT_TX,
  LED_EVENT_BADCRC
};

static LedEvent g_ledEvent = LED_EVENT_NONE;
static unsigned long g_ledEventUntil = 0;
static int g_scanPos = 0;
static int g_scanDir = 1;
static unsigned long g_lastLedStep = 0;

/* ============================================================
 * LOG
 * ============================================================ */

static void say(const String &s)
{
  Serial.println(s);
}

static void sayf(const char *fmt, ...)
{
  char b[220];
  va_list ap;
  va_start(ap, fmt);
  vsnprintf(b, sizeof(b), fmt, ap);
  va_end(ap);
  say(String(b));
}

/* ============================================================
 * PIXELS
 * ============================================================ */

static void pixelsOff()
{
  pixels.clear();
  pixels.show();
}

static void pixelsAll(uint8_t r, uint8_t g, uint8_t b, uint8_t w = 0)
{
  for (int i = 0; i < PIXEL_COUNT; ++i) {
    pixels.setPixelColor(i, pixels.Color(r, g, b, w));
  }
  pixels.show();
}

static void startupPixelTest()
{
  pixelsAll(40, 0, 0, 0);
  delay(250);

  pixelsAll(0, 40, 0, 0);
  delay(250);

  pixelsAll(0, 0, 40, 0);
  delay(250);

  // RGBW proof: WHITE channel only.
  pixelsAll(0, 0, 0, 35);
  delay(350);

  pixelsOff();
}

static void triggerLedEvent(LedEvent ev)
{
  g_ledEvent = ev;
  g_ledEventUntil = millis() + LED_EVENT_MS;
}

static bool coreHealthy()
{
  // RS485 is passive in this test; no received packet is not a fault.
  return g_sdOK && g_sdWriteOK && g_ethLink && g_haveIP && g_audioConfigured;
}
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

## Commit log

2026-07-31 סידור שם readme
2026-07-31 נסיון ראשון אחרי הסדר שעשינו
2026-07-31 מיקרופון עובד במקם כרטיס זכרון
2026-07-31 אחינו מוזהה
2026-08-02 הצלחה בשמיעת רדיו חלש מאד
2026-08-03 temp sensor + rtc battary
2026-08-06 לילה ראשון עם מסג
2026-08-08 PCB START
    [bedbox_carrier.kicad_pcb, bedbox_carrier.kicad_sch]
2026-08-09 Handout Rev 12 in Hebrew RTL, panel_ira TEST 028, panel_shemi TEST 082, fan tile
2026-08-15 שומעים גלגלץ בחדר שינה מהאינטרנט
2026-08-27 24 remote decoding
    [remote_codes.xlsx]
